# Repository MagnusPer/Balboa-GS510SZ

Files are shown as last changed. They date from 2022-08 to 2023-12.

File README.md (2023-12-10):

# Balboa-GS510SZ with panel VL700S

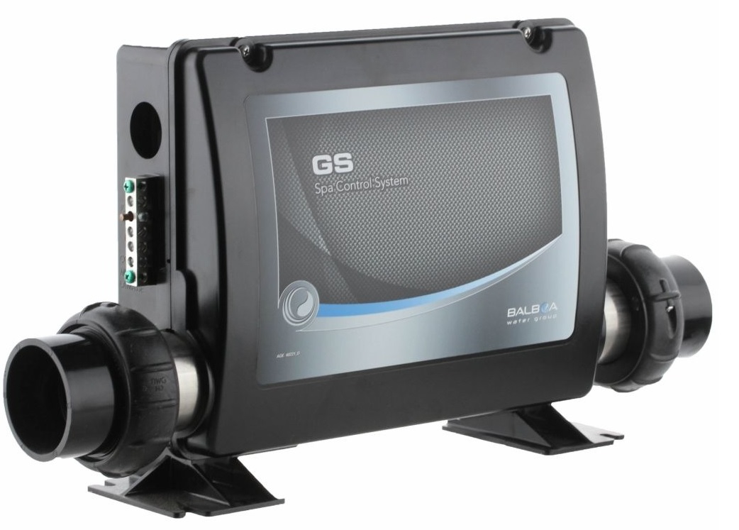
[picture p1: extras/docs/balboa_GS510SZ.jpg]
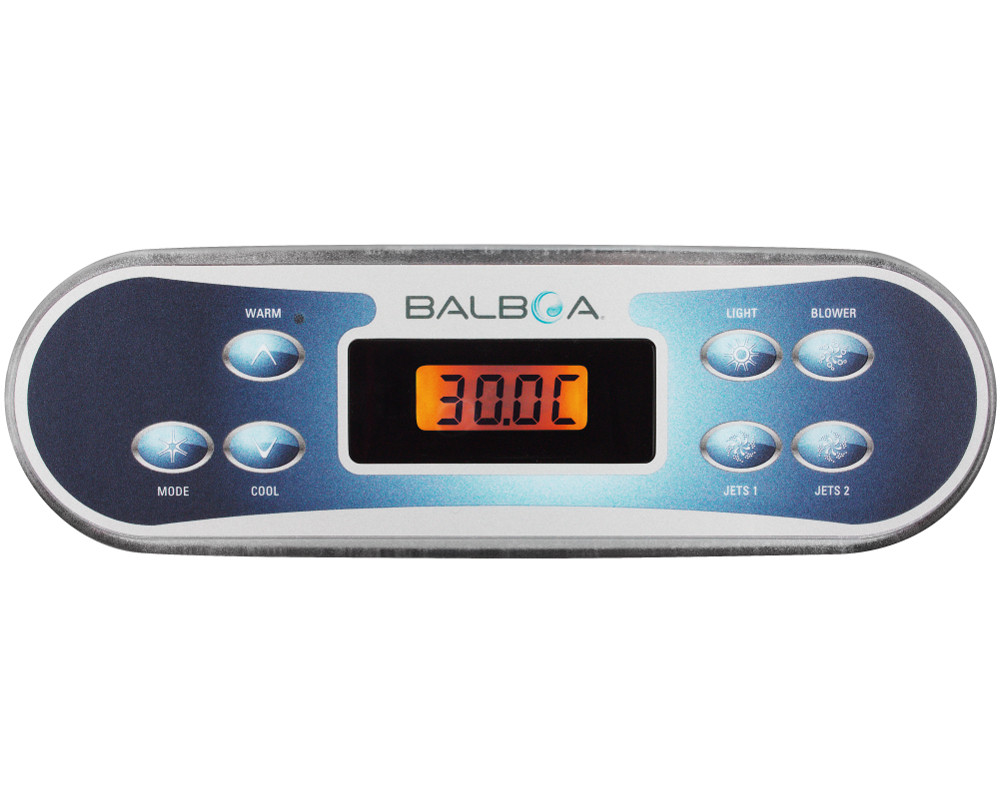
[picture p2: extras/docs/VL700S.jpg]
 

## Software
### version 1.3
 - New example sketch for Home Assistant users, thank you [netmindz](https://github.com/netmindz)   

### version 1.2
 - Updated a failure of the intepretation of "9" in `Balboa_GS_Interface.cpp`
 - Changed to [ElegantOTA](https://github.com/ayushsharma82/ElegantOTA) in `Balboa_GS_MQTT.ino` 
 - Added `Stop` and `Reset` MQTT interface in `Balboa_GS_MQTT.ino` 
### version 1.1 
 - New function `updateTemperature` added to set a temperature value instead of "push" button x number of times
 - Balboa_GS_MQTT sketch updated with [AsyncElegantOTA](https://github.com/ayushsharma82/AsyncElegantOTA)
### version 1.0 
- Basic functionality to read and set status using a **Balboa_GS** developed library. Two examples are provided, first with simple read and set functionality and the second using MQTT for remote access.

## RJ45 pins
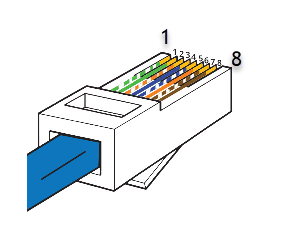
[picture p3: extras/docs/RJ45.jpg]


| PIN | Description | 
| --- | ---|
| PIN 1 | Functionality unclear!  |
| PIN 2 | Functionality unclear!  |
| PIN 3 | Button data |  
| PIN 4 | GND |
| PIN 5 | Display data | 
| PIN 6 | Clock |
| PIN 7 | 5 VDC |  
| PIN 8 | Floating output |

## Measurements 

### PIN 1 and 2 
PWM output from control system, same on both pins. Unclear functionality for these PINs still! Maybe some internal light supply? <br />  
50Hz, pk-pk=18v, mean 5V

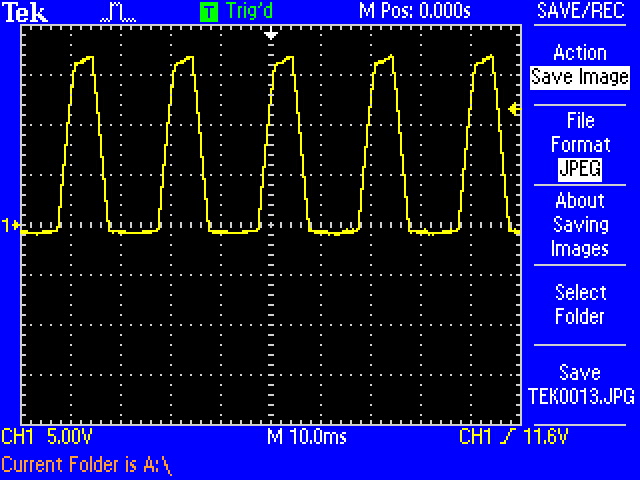
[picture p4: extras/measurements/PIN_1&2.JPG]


### PIN 6 (Yellow - clock), PIN 5 (Blue - display data), PIN 3 (Pink - button data) 

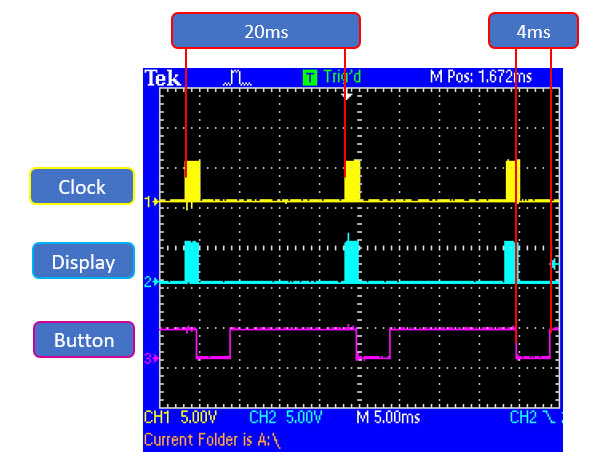
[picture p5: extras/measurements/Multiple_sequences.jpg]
   

<p align="center">
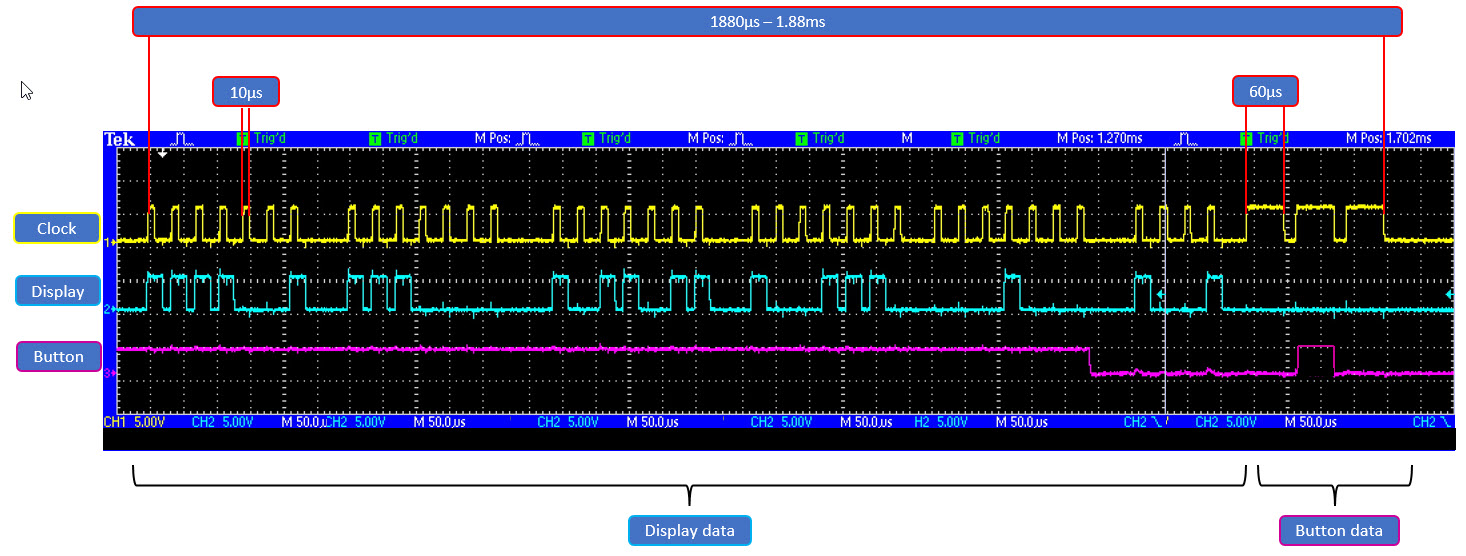
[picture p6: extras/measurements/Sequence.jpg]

</p>

#### Conclusion
- The clock is pulsing 7 times for each chunck of display data, totaly 39 bits and 3 times for button data. A complete cycle 42 pulses. <br />
- Totaly of 6 display data chunks in each cycle <br />
- Each cycle is repeted every 20 ms <br />
- One total cycle duration 1.88 ms
- Bit duration for display data is 10 microseconds for display data <br />
- Bit duration for button data is 60 microseconds <br />

#### Display Data
Display shows **37.5C** - How does that translates into the bitstream? The first 4 chunks is coded in BCD to 7 segment LCD (see reference) but only with 7 bits sinse the LSB always is (0). <br />
3 = 1111001(0) = 0x79  (Chunk 1) <br />
7 = 1110000(0) = 0x70  (Chunk 2) <br />
5 = 1011011(0) = 0x5B  (Chunk 3) <br />
C = 1001110(0) = 0x4E  (Chunk 4) <br />

| Chunk 1 - bit(0-6) | Chunk 2 - bit(7-13) | Chunk 3 - bit(14-20) | Chunk 4 - bit(21-27) | Chunk 5 - bit(28-34) | Chunk 6 - bit(35-38) | 
| --- | --- | --- | --- | --- | --- |
| LCD segment 1 |  LCD segment 2 | LCD Segment 3 | LCD segment 4 | 28 - Button down/up  | 35 - Heater | 
| | | | | 29 - ? | 36 - Pump 1 | 
| | | | | 30 - ? | 37 - Pump 2 |
| | | | | 31 - Standard mode | 38 - Light |
| | | | | 32 - ? | |
| | | | | 33 - ? | |
| | | | | 34 - ? | |
   
#### Button data 

|  Button |  Decoding bit(0-2) | 
| --- | --- |
| Mode | 0 0 1 |
| Temp up | 1 0 0 |
| Temp down | 1 0 1 |  
| Light | 0 1 1 |
| Pump 1 | 1 1 0 | 
| Pump 2 | 0 1 0 |
| Pump 3 | 1 1 1 |  

## Wiring

Since the display and controler unit hardware design is unknown an OR-gate is used to prevent damage if simultaneous HIGH/LOW levels from display and Arduino.

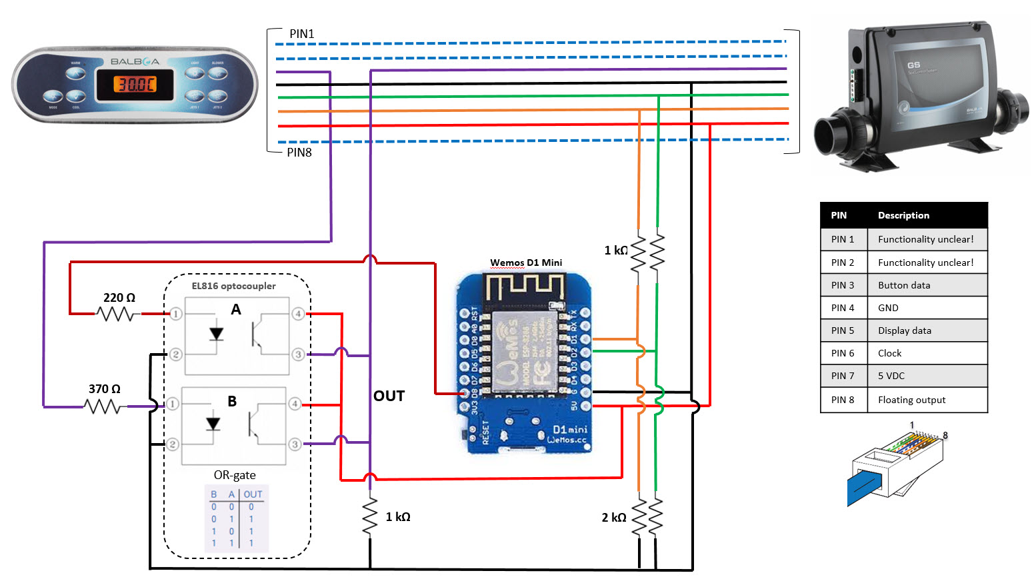
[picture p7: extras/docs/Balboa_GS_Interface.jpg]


## PCB fabrication

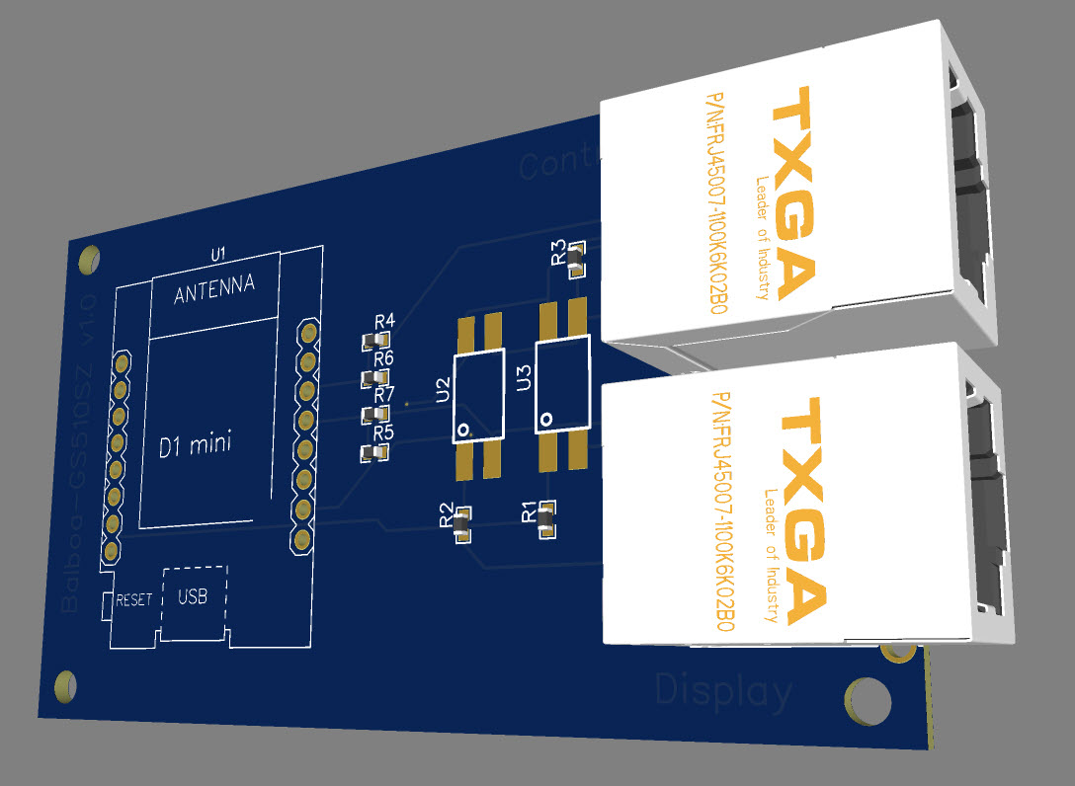
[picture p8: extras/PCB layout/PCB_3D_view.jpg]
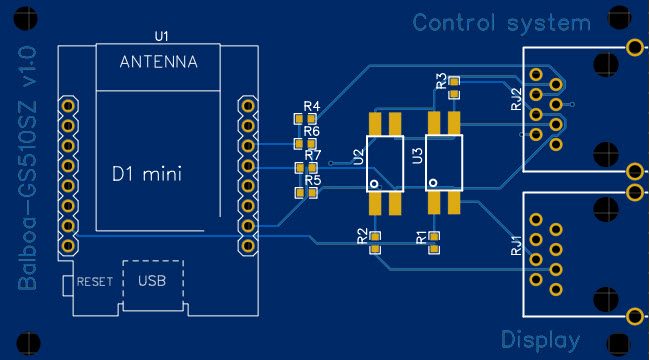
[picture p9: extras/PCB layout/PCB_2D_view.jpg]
 

Gerber files located here: [PCB Balboa-GS510SZ](https://github.com/MagnusPer/Balboa-GS510SZ/tree/main/extras/PCB%20layout )

## References of great help!
- https://github.com/NickB1/OpenSpa/blob/master/documents/Balboa/Balboa_Display_Measurements.pdf
- https://www.olivierhill.ca/archives/72-The-Internet-of-Spas.html
- https://create.arduino.cc/projecthub/meljr/7-segment-led-displays-102-using-a-shift-register-6b6976

## Other Balboa projects 
- GL2000 Series https://github.com/netmindz/balboa_GL_ML_spa_control
- BP Series https://github.com/ccutrer/balboa_worldwide_app
- GS523SZ https://github.com/Shuraxxx/-Balboa-GS523SZ-with-panel-VL801D-DeluxeSerie--MQTT

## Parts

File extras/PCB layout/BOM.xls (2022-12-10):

Comment | Designator | Footprint | JLCPCB Part #
FRJ45007-1100K6K02B0 | RJ1,RJ2 | RJ45-TH_FRJ45007-1100K6K02B0 | C2834418
EL816S1(D)(TA)-F | U2,U3 | OPTO-SMD-4P-4.58X6.5 | C181884
220 | R1 | R0603 | C22962
1k | R3,R4,R5 | R0603 | C21190
2k | R6,R7 | R0603 | C22975
370 | R2 | R0603 | C25194

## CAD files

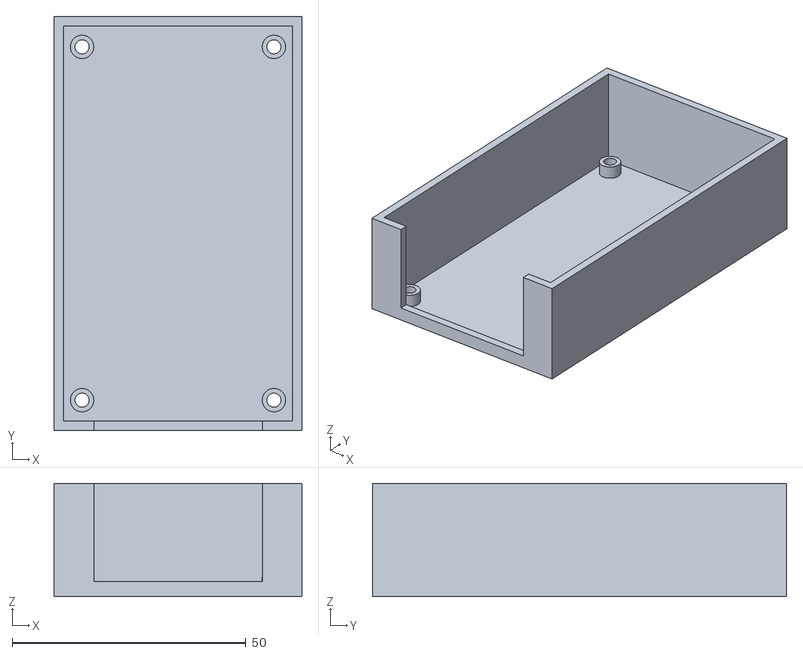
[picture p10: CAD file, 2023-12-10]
extras/Bottom.stl
53.0 x 88.5 x 24.2

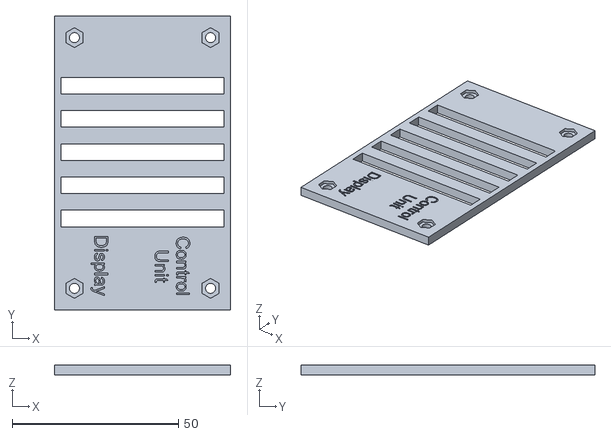
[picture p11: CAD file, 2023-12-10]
extras/Top.stl
53.0 x 88.5 x 3.00

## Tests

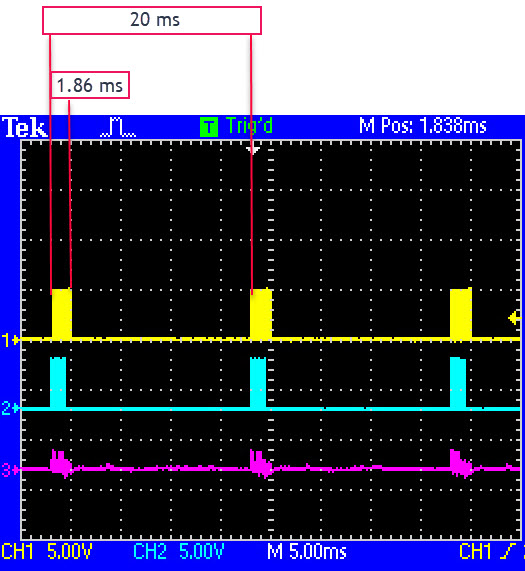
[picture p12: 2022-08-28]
extras/measurements/Cycles.JPG

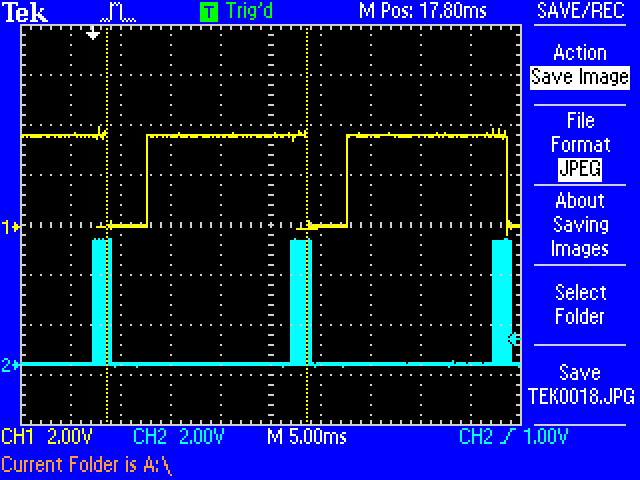
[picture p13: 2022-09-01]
extras/measurements/PIN3.JPG

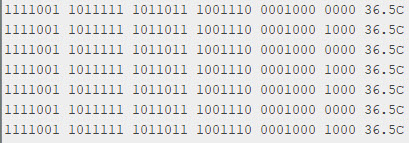
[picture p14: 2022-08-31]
extras/measurements/data_capture.JPG

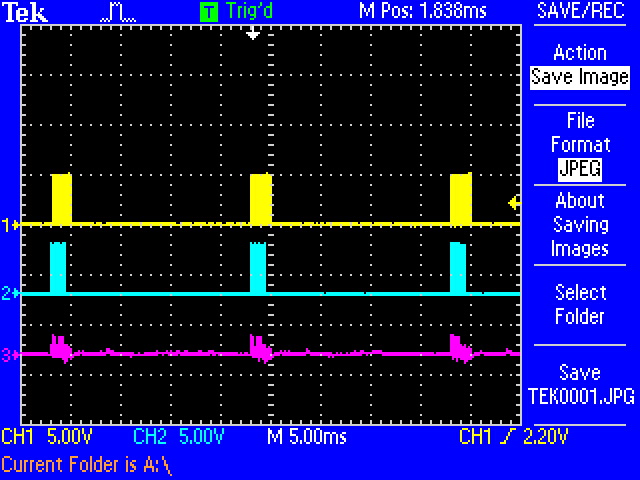
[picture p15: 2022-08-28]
extras/measurements/TEK0001.JPG

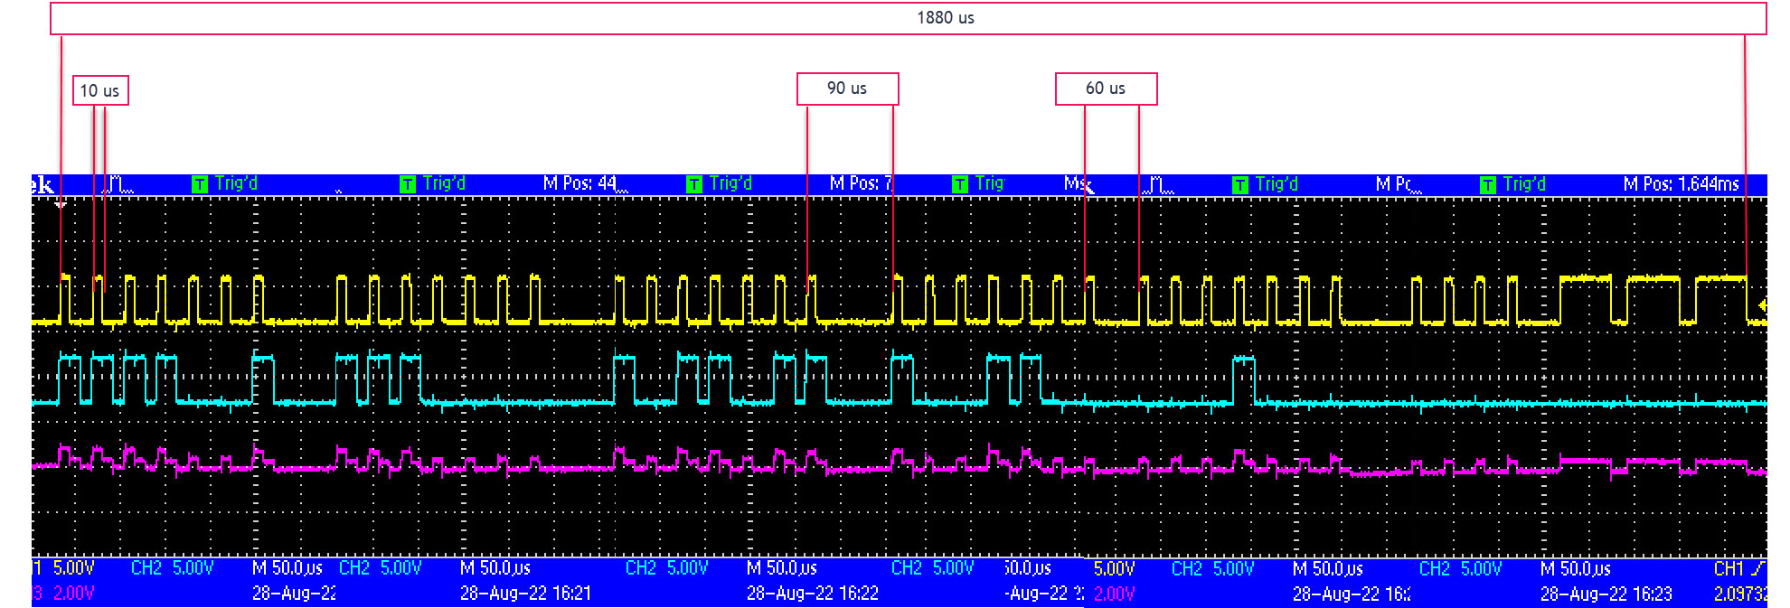
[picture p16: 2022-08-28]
extras/measurements/Complete Sequence.JPG

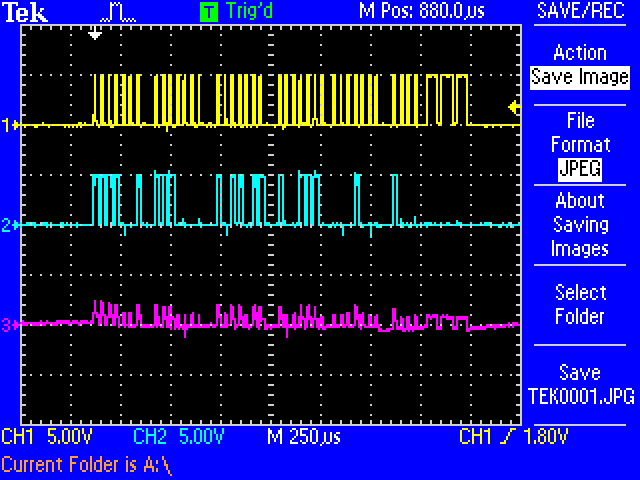
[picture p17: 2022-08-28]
extras/measurements/PIN6-PIN5-PIN8.JPG

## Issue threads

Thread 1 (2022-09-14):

Testing help

wictorwilen, 2022-09-14:
@MagnusPer - if you need a tester/contributor, please share the code. I'm all set with hardware to test this out!

MagnusPer, 2022-09-14:
Hi there!
First software delivery Phu! Have tested myself a couple of hours and it seems to work as expected so far. Mainly happy case scenario but anyway something is up and running :-)

Try this basic version out and give me some feedback and you are super welcome to contribute.

netmindz, 2022-09-15:
Great work turning this round so quickly

MagnusPer, 2022-09-16:
@netmindz - Thank you! Most of it was actually working with the oscilloscope to understand how the logic was connected. The library has now a limited scope of functionality as a start.

netmindz, 2022-09-16:
You say limited, but from quick look it appeared you had mapped all that the control panel can do.

Only bit that comes to mind for the library would higher level functions like setting a specific temp rather than just +/-

MagnusPer, 2022-09-16:
That is exactly what I working on now to set a specific temp instead of "push" the button x number of times

wictorwilen, 2022-09-16:
If electricity prices is decent this weekend I'll fill up my spa and start testing this! Amazing job so far

MagnusPer, 2022-09-16:
@wictorwilen - Before filling up the SPA with water you might test first the communication working as expected. I can imagine you will have some fault codes in the LCD display such low water etc. But at least you see that it works.

INFO: My top priority on this project is to be able to control when in time during the day the heater should be activated. This in order to save to money which i can spend on something more funnier:-)

netmindz, 2022-09-16:
Yeah that's why I want to get write access to my GL series. Have home assistant put into sleep overnight if the weather looks unsuitable the following evening or weekend day

Closed 2022-09-27.

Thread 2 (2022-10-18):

esphome.io support?

wjcloudy, 2022-10-18:
Hi, thanks for sharing this, going to try this on my own unit!

Just a thought, have you looked at writing this as a custom component in the popular esphome.io ecosystem?
This way the wifi stability, MQTT, HomeAssistant support, OTA, web UI & central management problem is all solved for you!

https://esphome.io/components/sensor/custom.html

MagnusPer, 2022-10-19:
Hi @wjcloudy
Happy you have found this library and please use and provide your feedback. I have used this for a couple of weeks and it serves my main purpose to control when in time the heater should be activated or not.

Your question on using esphome - I have myself not used and by that not have any experience. Feel free to adapt the example code and make a proposal which we can evaluate and provide to the community as an additional example.

wjcloudy, 2022-10-19:
Thanks, will look into it. I also want to use for controlling heater on time. I presume you achieve this by ramping the temp up during periods you want to use power and down at other times?. Have you found a way to adjust the minimum set point?

MagnusPer, 2022-10-19:
Yes - I change the temperature dependent if I want to heat or not. My settings is right now to toggle between 37 and 27 degrees depending on electrical price using the Homey automation Hub

MagnusPer, 2022-12-13:
CLOSED - No activity

Closed 2022-12-13.

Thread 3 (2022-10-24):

VS series compatibility?

kernel610, 2022-10-24:
Any idea if this should work with the VS series Balboa controllers that also use the RJ45? I was about to order the PCB to test it out but wanted to see if you've heard anything from others or foresee any challenges? If not, I can test and provide back an update.

Is there a Discord or someone to provide updates if I test it as opposed to cluttering up your Issues?

MagnusPer, 2022-10-25:
Hi,
Unfortunately no idea if the Balboa **VS** system is compatible with the GS or not. But after some minutes googling the control system PCB seams at least similar.

As information there are other repositories for other balboa systems, you might can go through those and see if any have asked the same question as you have:
Balboa **GL** -  https://github.com/netmindz/balboa_GL_ML_spa_control
Balboa **BP** -  https://github.com/ccutrer/balboa_worldwide_app

I haven't set up a Discord area for this development, I think we can trace it through issues within this repository so far. But if the community grows, I'll keep that in mind

netmindz, 2022-10-25:
If you look at the manual for at least some of the VS series to see what Topside panels they are compatible with, then look at what control units they work with, I see GS units listed.

What is your exact model of controller and topside panel?

The key thing really is both the GS and GL project are really emulating the panel for their respective controllers

MagnusPer, 2022-10-25:
When reading the topside panel documentation I use for my GS-serie [VL700S](https://github.com/MagnusPer/Balboa-GS510SZ/blob/main/extras/docs/Balboa-Panel-VL700S.pdf) I found here that both GS and VS control system is compatible

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

By that I think this library should work also for the Balboa **VS** serie

kernel610, 2022-10-25:
Controller model is VS501SZ which appears to be covered with the link and screenshot Magnus provided. Topside panel is in rough shape but documentation for the controller shows VL401, VL403, or VL200.

I'm going to order the PCB and give it a try! I'll keep you updated through this thread. Thanks again for the effort put into this!

MagnusPer, 2022-10-25:
Minimum order is 5 PCBs, I have one available which I could send by post to you. Give me your adress by mail magnus_p@live.se

Closed 2022-12-23.

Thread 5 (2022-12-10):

BOM list for PCB?

thoby1, 2022-12-10:
Very interesting project. Thought I would test this, but have limited electronics knowledge.
Could you attach a BOM list so that it would be easier to order all the necessary components for the PCB board?

cbakkerprive, 2022-12-10:
Wow, cool! I too am definitely interested in the BOM list.

MagnusPer, 2022-12-10:
I have been using this for a couple of months now and it works as I expected with my main purpose to heat the SPA during the cheapest hours.

The BOM list hopefully explained in the [Wiring](https://github.com/MagnusPer/Balboa-GS510SZ#wiring) section. What you need is the following:

3 pcs  - 1 kOhm resistor
2 pcs  - 2 kOhm resistor
1 pcs  - 220 Ohm resistor
1 pcs  - 370 ohm resistor
2 pcs -  EL816 optocoupler
1 pcs - Wemos D1 mini
1 pcs - RJ45 cable

thoby1, 2022-12-10:
Cool to hear it works! The use case with turning the heater on and off during low and high prices was exactly what I had in mind.

When it comes to purchase of parts there seems to be so much extra specifications that makes it hard to choose. For resistors for example there are spec for Voltage and Watt. Take the 2kOhm for example, will this item work:
**NQ06W4F2001T5E**
[](https://jlcpcb.com/partdetail/1050181-NQ06W4F2001T5E/C965049)

MagnusPer, 2022-12-10:
I uploaded the BOM list [PCB layout](https://github.com/MagnusPer/Balboa-GS510SZ/tree/main/extras/PCB%20layout) I used when I purchased the PCB, hope this helps

cbakkerprive, 2022-12-10:
Thank you!
Can you also provide the CPL file so I can order assembled from JLCPCB?

MagnusPer, 2022-12-10:
@cbakkerprive - Not sure what you mean with the CPL file but I guess its the [PickAndPlace](https://github.com/MagnusPer/Balboa-GS510SZ/blob/main/extras/PCB%20layout/PickAndPlace_PCB_Balboa-%20GS510SZ_2022-12-10.csv) file?

cbakkerprive, 2022-12-11:
Thanks MagnusPer!
Indeed I did the PickAndPlace File.
As stated I try to order the assembled PCB from JLCPCB.
I did uploaded the 3 files to JLCPCB, but unfortunately after selecting the BOM and the PickAndPlace file (and select Next) I get the following error:

_Incorrect format
File parsing timeout. Please try again later.__

Maybe I should try to open the gerber file in the EasyEDA designer myself.
Thanks anyway.

MagnusPer, 2022-12-11:
@cbakkerprive - I think it's better you try yourself to create the PCB in e.g. EasyEda with the help of the Gerber files provided. I remember I needed to replace and change the optocouplers component due to missing parts in the factory. When you succeed to place the order please help others here by attaching your PCB production files.

If you have any questions I'm here to help the best I can!

thoby1, 2022-12-30:
I havesuccessfuly completed a order at JLCPCB with the "BOM.xls" and "PickAndPlace_PCB_Balboa-GS510SZ_2022-12-10.csv" file. This issue can be colsed.

Closed 2022-12-30.

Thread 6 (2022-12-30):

Support for VL600S panel?

thoby1, 2022-12-30:
I tested the software against a VL600S panel. It seems to give the correct status messages, but when I try to send commands the display stops working. Then only a gray background is displayed without any text. When this happens, I have to turn off the power and disconnect the circuit board with the Arduino. Then when I turn on the power again with the original setup, the display works fine. Have tried the "stop" and "reset" function, but it has no effect on the issue.

MagnusPer, 2022-12-30:
To start somewhere...
If you press the display button when the circuit board is connected, does the e.g. jets starts or temperature change? by this I want to understand if the connection is OK between the controller unit and the display with the circuit board connected.

thoby1, 2022-12-30:
I am using the MQTT example.

Looks like the same thing happens when you press the control panel. Also managed to provoke the error by just waiting a few minutes without pressing a single button or sending any command. I think you are on to something about there not being a good connection between the control unit and the display, when the circuit board is connected. I have tested the TP cables with a network cable tester and they worked fine. Also tested the circuit board with the same cable tester. There I got connection on all pins except for pin number 3.

MagnusPer, 2022-12-31:
Yes - something is wrong since you not manage to press the display button.

Have you used ordinary TP cables? They normally have crossed lines!

You can not measure line 3 since the optocoupler requires 5V to close. you could provoke that by manually add 5V and GND on the bench to check

thoby1, 2023-01-01:
- I’m using the original flat cable that comes from the display and my own twisted pair cat 6 straight cable to the control system. The cables has a straight connection on etch pin. Should I use only flat cables and not the one that has twisted pairs? The two cables work together if I disconnect the circuit board and connect them with a RJ45 cable extender.

- Tested the optocoupler by giving it 5V from line 3 on RJ1. That gave me a signal on line 3 from RJ2.

- I have wired the display the RJ1 connector (it is marked with “Display” on the circuit board) and the control system to RJ2.

I see that I am using version 3 of the Wemos D1 mini, but in your wiring diagram it shows version 4. Will that be a problem?

To be more specific in the issue. The system seems to be working fine during the hot tub startup sequence when I turn the fuse on. Then I get MQTT messages with water temperature and pump status etc. After the startup the display begins to flash between showing the water temperature and just a gray background. Eventually just ending up in showing a gray background. This happens regardless of me sending any commands or not. To correct the issue I have to put everything back to the origianl setup. Since the cables work fine with just a cable extender and not on the circuit board could there be too much resistance on some of the pins?

MagnusPer, 2023-01-02:
Seems the TP-cables are ok when a RJ45 cable extender is used. I think it's more likely something with the circuit board. If we suspect the Wemos then you can disconnect that from the board since the board should work without it, check the [wiring diagram](https://github.com/MagnusPer/Balboa-GS510SZ#wiring).

thoby1, 2023-01-02:
Tested a circuit board without Wemos and it worked fine. All buttons and display worked as they should.

Should the Wemos have an external power supply? While testing I only have only connected the two TP cables. They have 5V on pin 7 and ground on pin 4. I was wondering if the Wemos draws too much power.

MagnusPer, 2023-01-02:
Ok, we are closing in!
To be sure about the Wemos you are using. Is this the ESP8266 or the newer ESP32 version?
A guess is the Wemos restarts and might cause the problem. To check this connect your computer an log via the serial interface to check what’s happening

thoby1, 2023-01-04:
I have now tested the Balboa Read example software and connected it to a PC for debugging.

It worked fine from the software side. I saw the status and could start and stop the pump, turn lights on and off, etc.

When I pressed the display, it behaved strangely. It didn't always react and if it did it seemed as if the buttons had been given a different function. If I pressed “Pump 1” it looked like I pressed “Temp up”.
Finally, I ended up with the same error. Showing a gray background in the displayed again.

The difference in this test scenario is that Wemos is supplied with external power from the USB cable and that this software do not use the WiFi module. So maybe there is something with the power?

Also, if I used the board “LOLIN(WeMos) D1 R1” the software did not work. I ended up using the “LOLIN(WEMOS) D1 R2 & mini” board config.

MagnusPer, 2023-01-04:
I just thinking about the VL600S (6 button) panel and the difference compared to the VL700S (7 button) I have - when reading the [Balboa-GS510SZ](https://github.com/MagnusPer/Balboa-GS510SZ/blob/main/extras/docs/Balboa-GS510SZ.pdf) documentation there are some jumper settings to configure the control system with depending on panel configuration. And if this effects the way the commands is sent??

> It worked fine from the software side. I saw the status and could start and stop the pump, turn lights on and off, etc.

Need to double check this, do you mean when entering the write commands using the serial monitor the the activations is correct?

> When I pressed the display, it behaved strangely.

This is really strange since the signals should go straight through the optocoupler - see the [wiring diagram](https://github.com/MagnusPer/Balboa-GS510SZ#wiring). Like when the Wemos was dismounted.

Did you order more then one circuit board, have you tried another one?

thoby1, 2023-01-07:
I have limied knowlage about this but I think there is something wrong with the circuit board. When I tested with voltage on the Wemos, it outputs 5V on pin 7 and 4 (ground) (RJ2). If I did the opposite and put voltage on pin 7 and 4 at RJ2, I only got about 1V on pin 8 and 7 on the Wemos. Suspect that there may be something wrong with the common ground somehow. Because if I tested pin 8 on Wemos against pin 4 on RJ2, I got 5V. Tried different places where I had access to common ground such as on one side of R3 I also only got 1V.

When it comes to the jumper settings on the motherboard such as J12, I interpret it as which software should run. I use this setting:

**Jumper must be on Pins 1 and 2 for GS51xZ/GS52xZ/GS5xxSZ/GS5xxDZ software.**

I have a spare circuit board that I have tested without Wemos and it works fine. Have ordered a new Wemos v4.0 now. Will test again when I get it. I believe that it will work then, because when I tested with the Read example and sent commands via the serial interface, I was able to set the temperature, turn the pump on and off and turn on the light. The Wemos never seemed to restart.

MagnusPer, 2023-01-07:
Tricky when I not myself can measure the circuit board. What I at least have done is to update the [wiring diagram](https://github.com/MagnusPer/Balboa-GS510SZ/blob/main/README.md#wiring) to clarify the Vcc +5V and ground connections.

You are on the correct track, verifying piece per piece, at least we have learned and have zoomed in where the problem is located. If possible, please take a picture on your board with the Wemos mounted and paste it here.

Give me an update when you have tested with the new Wemos.

thoby1, 2023-01-13:
I got the same error now with a new circuit board with v.4.0 of Wemos. My problem is that I don't get enough voltage to the Wemos from RJ1 or RJ2. My test setup is a USB mobile charger which provides 5v. It works if I connect the USB to the Wemos, but if I apply voltage to pins 7 and 4 on RJ1 or RJ2, I only get about 1v on the Wemos. I have soldered all the pins from the Wemos firmly to the circuit board, although from the drawing only pins 3, 4, 7, 8 and 15 needs to be connected. Will that be a problem? Holes have been made for all the pins on the circuit board, so I assumed that the ones that are not in use are isolated.

Have attached a picture of the first circuit board. The soldering doesn't look so good after I've tried soldering the Wemos off and on again.

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

MagnusPer, 2023-01-13:
The unused pins is not connected to anything, no problems to solder them.

When measure with a standard multimeter it takes the average of the voltage, since it is a communication line you will never have 5V since this is the peak value.

I need to do my own bench test setup to guide you further. I will be back home on Sunday, so expert som days until I have some data to provide.

But until then - I tried to zoom in on the Wemos board to look after some data, can you read ESP8266 or ESP32 on the chip?

thoby1, 2023-01-24:
Installed version 4 of Wemos LOLIN D1 mini [https://www.wemos.cc/en/latest/d1/d1_mini.html](url) on a diffrent circuit board and now it is working as expected. Guess I was just unlucky with either my old Wemos or the circuit board. Regardless. The VL600S display panel can also be used with this project.

Closed 2023-01-24.

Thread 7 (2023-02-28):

Compability with GS501Z and VL200?

richardtjena, 2023-02-28:
Hi!

I have a Balboa GS501Z-control system with VL200 duplex display which uses RJ45 but only have four buttons.

Do we know if the data protocol is the same regardless if the display is a Duplex- (GS5xxZ), Standard- (GS5xxSZ), or Deluxepanel (GS5xxDZ-unit)?

BR

MagnusPer, 2023-02-28:
@richardtjena  - Welcome in here to this repository!

When reading the specs of the control system [GS501SZ](https://www.balboawatergroup.com/getdoc.cfm?id=2160) and [GS510Z](https://www.balboawatergroup.com/getdoc.cfm?id=2169) there are some differences as you mentioned where the VL200 panel has less buttons.

To be honest, I have no idea if this will work or not, but my guess based on the documentation is that it should work as both features like the circuit board layout seem to be pretty similar.

The best answer is if you make a try - The hardware cost is where low!

MagnusPer, 2023-03-03:
Closing this issue since this repository does not support Balboa GS501Z-control system with VL200 panel

richardtjena, 2023-04-10:
@MagnusPer was it a user with a public repo? Any chance you can point me to his direction.

I also thought about flipping the J12 jumper in the control unit but don't know if it would have any effect without changing the ROM.

StarkJohan, 2024-04-15:
I have the same setup and the protocols must be very similar. To avoid doing the work someone else already has done, please put me in contact with anyone that might help: johan@punktvvv.se

netmindz, 2024-04-18:
The way to know about compatibility is to think about the fact we are emulating a panel, so if you look at which official panels are compatible with which controllers you know that they must use the same communication

StarkJohan, 2024-04-21:
I'm using the VL240 panel and the protocol is indeed similar but there's a few big differences. I've outlined them in another issue.
In short it will not be possible to use this repo or the hardware without rather big changes.

Closed 2023-03-03.

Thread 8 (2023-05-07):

Confirming ground pin?

techoguy, 2023-05-07:
Hi, just curious how you were able to confirm which pin was the ground. I'm currently sniffing my spa panel bus and it seems to have a similar protocol (though different) compared to yours. Mine has only 3 groups of 7 data and handles the buttons the same way as yours. But I'm trying to confirm which pin is the ground pin.

My protocol has a different odd case when the clock is held high until the next batch of data. Still trying to figure out why it does that (it might be indicating the heater on LED on the panel, but not sure yet).

I'm still annalizing my data to see how I want to implement this but seems like I might be able to use yours as a baseline. Thanks for the work you've already put into this.

MagnusPer, 2023-05-08:
Hi,
Great this repository can advice and help you with your project. The work I did was more based on "exclusion method" where I finally understood the SPA behavior and the usage of each pin. To find the ground pin you can measure against the control unit ground which should have the same.

netmindz, 2023-08-07:
What model do you have @techoguy ?

One way to confirm ground is with the power turned off use a multi meter to check for continuity between that pin and the ground plane of the PCB

techoguy, 2023-08-09:
@netmindz I have a Sundance Camden with 780 Series I-Touch Controls. I think it's about 10-15 years old. Below is a picture of the current signals.

- there is an 8 pin connector going to the control panel and an empty RJ45 plug
- Pins 1-6 are the same between both connectors, but pins 7 and 8 are not
- the control board sends a sequence every 100ms (3 bytes of data to the touch panel, 7 bits from the touch panel for button presses)

**Pins:**

1. 5v
2. GND
3.  Data
4.  Clock
5.  Select (active low)
6. Button Data
7. (Not sure) maybe a device select?
8. (Not sure) maybe a device select?

Signal Example:
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

Picture of control board connectors:
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

Closed 2023-08-06.

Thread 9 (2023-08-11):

how to determine if set temperature is displayed vs current water temperature?

techoguy, 2023-08-11:
Hi @MagnusPer I'm reading over the code to see if I can start from your code or if it'll be easier to start from scratch. Curious, on your display, when you press up or down to change the temperature and the display temporarily displays the set temperature vs the current water temperature, how does the ESP device know which temperature is displayed? On my spa, there appears to be no pattern or indicator in the messages to the control panel when the set temperature is displayed vs the current temperature which means I can't really tell which temperature is displayed unless I also have the button signals as inputs to know someone at the panel is changing the set temperature. curious how you're dealing with this.

Thanks!

MagnusPer, 2023-08-11:
Hi,
There is a trigger `displayButton` when the up/down button is pressed on the display. By this I can understand if it’s the water temperature or set temperature that is shown.

Closed 2023-08-13.

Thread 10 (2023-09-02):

HowTo

duczz, 2023-09-02:
Hey, i have this baboa Whirlpool too and wanna try these, but iam missing a HowTo.
Currently i have flashed your Project to a wemos Mini (with my settings) but i have no entitied in the homeassistant mqtt server.

What are ne next steps? Docker witch bwa?

netmindz, 2023-09-02:
Have you tried the simple read example first to confirm the basic setup works first?

You don't mention if you have any existing Home Assistant setup already on place. You will need that and follow an appropriate guide to setup MQTT with Home Assistant

There are many different ways for this depending on how/where you are running HA

Once that's setup, you should see the spa under MQTT inside HA

MagnusPer, 2023-09-02:
Hi and happy that you are interested in this library.

Firstly, Have you set your credentials in the code for the MQTT broker?
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

If so check that MQTT messages coming in from the SPA using a MQTT tool like http://mqtt-explorer.com/

duczz, 2023-09-02:
Thanks for reply guys.
I have a MQTT Integration on my homeassitant, these i have enters already in the config, thats why i see via MQTT Explorer the Spa Parameters, but not on homeasssitant
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

MagnusPer, 2023-09-02:
Sorry, I do not have HA instead I use Homey so the integration to HA using MQTT I can not help you with

duczz, 2023-09-02:
okay thank, so the next steps are only to let create the PCB layout and than put the j1 in the new medoul and j2 from the modul to j1 from the balboa right? not more to do?

netmindz, 2023-09-02:
You could use with HA with just the raw MQTT, but it's *much* easier if you have a proper device registered in HA

netmindz, 2023-09-02:
Ok, that's the basic read-only example up there now

![Uploading Screenshot from 2023-09-02 17-55-29.png…]()

duczz, 2023-09-02:
Perfect, the other will follow too?

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

netmindz, 2023-09-02:
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

netmindz, 2023-09-02:
Latest version with buttons too - untested as I don't own that tub

duczz, 2023-09-05:
to close the ticket, can someone answer my question?
so i need to let create the PCB layout and than put the j1 in the new modul and j2 from the modul back to j1 from the balboa right, than im finished?

can i control than the modies too and set the time for filter?

MagnusPer, 2023-09-06:
@duczz - Between the display and the control system there is a cable with an RJ45 connector. Disconnect that from the Control system and place PCB in between. You need to create/buy the cable with RJ45 connectors between J2 -> Control system, NOTE that should have straight lines and not crossed as in a normal TP-cable.

**DISPLAY**-------->(J1)  **PCB**  (J2)--------->**Control system**

There are no functions created to change modes or set filter times etc. The library however supports buttons to be pressed so theoretically it should be possible - see the section [button data ](https://github.com/MagnusPer/Balboa-GS510SZ#button-data)

I hope this mini guide will help you to get it up and running

duczz, 2023-09-06:
Perfect thank you Magnus.
@netmindz can you add all Buttons on this display to homeassitant? Than i can create automatisations to set mode / filtertimes etc.

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

netmindz, 2023-09-06:
I won't be adding any more to the code, if the buttons are supported by the library then it should be easy to follow the current examples.. If not, then update the library part of the code too

Create a fork then and then submit a PR

duczz, 2023-09-06:
@netmindz alright, thanks for the first homeAsssitant port steps.
@MagnusPer are you able to update these? it looks like all buttons would be exist. i'm to noobie to port these :(
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

MagnusPer, 2023-09-06:
Sorry, I don’t have the knowledge how the Home Assistant works. The library support the “Mode” button and what I see is included in the HA example. The only missing piece is to add a HA button to trigger the mode.

knogler, 2023-10-21:
@duczz have you found a solution?

netmindz, 2023-10-21:
To add a button for pump3, just copy and paste what's listed for pump2

```
pump2.setName("Pump2");
pump2Button.setName("Pump2");
pump2Button.onCommand(onButtonPress);

```

but name pump3. Do same for any other buttons you want such as Mode

netmindz, 2023-10-21:
As well as the definition of he button

`HAButton pump2Button("Pump2");`

knogler, 2023-10-21:
Thanks for the answer, I probably could have done that.

Unfortunately, setting the temperature is not displayed. somehow the variable “setTemperature” is missing from the homeassist file. And unfortunately I don't know how to create this in order to be able to regulate it.

duczz, 2023-10-25:
@knogler nope, i was not able to migrate it complet to HomeAsssitant. I think this will never be done ^^ (i'm no developer :/)

netmindz, 2023-10-30:
Try this version @knogler  https://github.com/MagnusPer/Balboa-GS510SZ/pull/13

duczz, 2023-11-09:
@knogler Could you test it successfully?

J0E-Cool, 2023-11-15:
Hi @all,
just a dumb question ;)  and sorry to reuse this chat...
I've already built the circuit on a stripboard 🙈, but now I'm thinking about, how I could test it with the still installed display VL100 and control board GS100... because, I guess, I've to adapt the programming.
Do you have some tips, lessons learned, how you did/do that?
Thanks :)

knogler, 2023-11-17:
Sorry for my late response. and thanks for coding. Unfortunately I haven't had time to test yet. I also have to see how I can get the software modified so that it runs with Balboa-MGS504DZ with panel VL700S (MAY800D). As soon as I have more information, I'll let you know.

netmindz, 2023-11-17:
The model of top panel shouldn't really matter too much as we are emulating a panel. So what matters most is compatibility with the controller and the protocol it's speaking. Different models in the same range should use the same protocol so it shouldn't need code change.

What you might find is that your tub might only have 1 pump not two, so you mind find that pressuring pump2 might trigger the blower, just as if you had the wrong overlay applied to your top panel for your particular configuration

MagnusPer, 2023-11-17:
> Hi @ALL, just a dumb question ;) and sorry to reuse this chat... I've already built the circuit on a stripboard 🙈, but now I'm thinking about, how I could test it with the still installed display VL100 and control board GS100... because, I guess, I've to adapt the programming. Do you have some tips, lessons learned, how you did/do that? Thanks :)

[@JOE-cool](https://github.com/J0E-Cool)

1) Start to just connect the circuit board to see everything works by manually press the panel buttons.
2) Easiest is to use example code [Balboa_GS_Read](https://github.com/MagnusPer/Balboa-GS510SZ/tree/main/examples/Balboa_GS_Read) and monitor via the serial monitor in [Arduino IDE ](https://docs.arduino.cc/software/ide-v2/tutorials/ide-v2-serial-monitor) if data is observed.
3) You can also use the example code via the serial monitor input to activate button presses according to the [code](https://github.com/MagnusPer/Balboa-GS510SZ/blob/main/examples/Balboa_GS_Read/Balboa_GS_Read.ino). Example is `4` to activate light
4) Now its time for remote access and automation. Depending of your knowledge and needs you have either the MQTT or HomeAssistant to work with

Good luck!

J0E-Cool, 2023-11-17:
@MagnusPer thank you, helps me a lot :) I hope I can continue this weekend, if the weather allows.
For the automation part, I've still to decide which one would fit best (don't have any in place), but step-by-step ;)

ggtimtom, 2024-01-05:
Hello, i also try to make my GS523DZ with Panel VL802DZ smart. I hope the protocol will be similar.
I will start when the weather is fine.

malu254, 2024-01-05:
> Hello, i also try to make my GS523DZ with Panel VL802DZ smart. I hope the protocol will be similar. I will start when the weather is fine.

Hello,
I think you need the Version from here https://github.com/Shuraxxx/-Balboa-GS523SZ-with-panel-VL801D-DeluxeSerie--MQTT
The Hardware which you need will be the same

duczz, 2024-01-13:
i try to build curretnly my lovelance Layout for the Summer. :)
Is it possbile to switch all Buttons with on/off function into a switch? what i need to edit for that?

MagnusPer, 2024-01-13:
I using NodeRed as dashboard for my home automation. In NodeRed I create buttons triggering the MQTT commands and subscribe to MQTT status. Simular should be possible to do using Lovelance.

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

duczz, 2024-01-13:
Thanksmagnus, I had hoped that we could change habutton to haswitch in the *.ino File direct but i dont know If this works. Maybe @netmindz know it? :) (i dont know If haswitch exists in this program language)

netmindz, 2024-01-13:
Yes there is @duczz  - see https://github.com/netmindz/balboa_GL_ML_spa_control/blob/7e193eb2708c2803dda82cae5e14056a8bfcb445/sensor/src/sensor.cpp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

The key thing is if you aren't just a button, then you need to know the current state, so it's not just swapping the type, but still pretty simple to do. See standalone example https://github.com/dawidchyrzynski/arduino-home-assistant/blob/main/examples/light/light.ino

netmindz, 2024-01-13:
I haven't tested the code, but it will be something along the lines of this https://github.com/netmindz/Balboa-GS510SZ/commit/4d32135e64c111bf3d1619eb5a832677b0603a93

duczz, 2024-01-14:
i have created on netmindz top tipps and example (much thanks without i cant do this) a new version, magnus can you create a new "Balboa_GS_HomeAssistant_DEV.ino" with this content? Would be create when someone can test it, my platine is not delivered :(
https://pastebin.com/7bMn9JAM

Someone knows why line 237 is commented out?

netmindz, 2024-01-14:
@duczz  - I'm not familiar with this specific controller, but I know on some spas the buttons have multiple functions, so even if there are switches for the pumps, it might not be wise also to remove the ability to send button presses, unless you know for sure that you only need mode and temp +/-

As for your onSwitchCommand, this needs to look to see **which** switch you are trying to change and then read the right state, you currently are reading the state of the light.

For example of checking the sender see https://github.com/netmindz/balboa_GL_ML_spa_control/blob/7e193eb2708c2803dda82cae5e14056a8bfcb445/sensor/src/sensor.cpp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

MagnusPer, 2024-01-14:
@duczz - When you have a working and tested example you can do a Pull Request and then I can approve it to be added

duczz, 2024-01-17:
okay thanks netminz, i tried, but that programming is to high for me im out ^^

awallace24335, 2024-01-27:
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

Just to confirm, can this be a normal patch cable or do the pairs have to be untwisted?

Thank you

knogler, 2024-01-28:
yes, it's a normal patch cable

jarnodrenth, 2024-11-24:
> Sorry, I do not have HA instead I use Homey so the integration to HA using MQTT I can not help you with

 Can you tell me what you use for homey?

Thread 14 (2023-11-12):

No possibility to buy the PCB via JLPCB

malu254, 2023-11-12:
Hello @MagnusPer , do you have any of your circuit boards for the Balboa control system left? Unfortunately, the Everlight Elec EL816S1(D)(TA)-F is currently not available for purchase via JLPCB. I already have the WemosD1Mini, so I would only need the board with the soldered SMD components.
If you still have a circuit board, how much would it cost including shipping to Germany?

Sorry for opening an issue, but Github has unfortunately removed the private message tab.

BR
malu254

MagnusPer, 2023-11-12:
@malu254  - Unfortunately I have no extra circuit board. But the JLPCB must be able to give you a proposal of a similar one since that optocoupler is very regular.

malu254, 2023-11-12:
Ok, too bad, unfortunately JLPCB can't suggest any others, or am I missing something?
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

Sh4d, 2023-11-18:
You can order them from China for relatively cheap - https://www.aliexpress.com/item/1005004701331738.html?spm=a2g0o.order_list.order_list_main.71.48c918022AP3k2

I got mine to Canada in about 2 weeks.

malu254, 2023-11-26:
@MagnusPer @Sh4d thanks for your Help. I managed it to switch the Optocoupplers to similar ones

kernel610, 2024-01-12:
> @MagnusPer @Sh4d thanks for your Help. I managed it to switch the Optocoupplers to similar ones

@malu254 What did you choose as the replacement that worked? I'm placing an order for another built board since my board shorted out from water intrusion in the box. I'm seeing the same stock shortage message on the octocoupler.

malu254, 2024-01-12:
> > @MagnusPer @Sh4d thanks for your Help. I managed it to switch the Optocoupplers to similar ones
>
> @malu254 What did you choose as the replacement that worked? I'm placing an order for another built board since my board shorted out from water intrusion in the box. I'm seeing the same stock shortage message on the optocoupler.

@kernel610 i used this ones: TLP785(BL-TP6,F(C

But if you want i would have to spare PCBs to Sell. They would be completely finished except for the D1 mini Micro Controller

PerssonNiklas, 2024-07-29:
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

You dont happend to have one left for sale perhaps? Old thread, worth a shot!

colsonpete, 2024-07-29:
I have a couple of the base boards (no D1 Mini) going spare if you are interested?

I haven't got one working yet, but suspect that's down to me trying to to get it to work between a GS515Z controller and a VL406T panel.

PerssonNiklas, 2024-07-30:
> I have a couple of the base boards (no D1 Mini) going spare if you are interested?
>
> I haven't got one working yet, but suspect that's down to me trying to to get it to work between a GS515Z controller and a VL406T panel.

Whats your email so we can get in touch?

colsonpete, 2024-07-30:
Hi NiklasMy email is peter Dot colson at pc-ss dot co dot ukKind regardsPeter ColsonOn 30 Jul 2024, at 21:54, PerssonNiklas ***@***.***> wrote:

I have a couple of the base boards (no D1 Mini) going spare if you are interested?
I haven't got one working yet, but suspect that's down to me trying to to get it to work between a GS515Z controller and a VL406T panel.

Whats your email so we can get in touch?
—
Reply to this email directly,
view it on GitHub, or
unsubscribe.
You are receiving this because you commented.Message
 ID: ***@***.***>

Closed 2023-11-26.

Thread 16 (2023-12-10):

What about the second connector on the board

Zetto12, 2023-12-10:
Hi Guys,

First of thank you for publishing this project. My Spa controller (Balboa CPGS501Z) has two identical RJ45 connectors. One the Display is plugged in but the other one is empty.

Does the D1 Mini need to go in line with the display or can it be connected directly to the second port? I believe that is where the original WIFI controller is connected to.

Thank you

MagnusPer, 2023-12-10:
@Zetto12 - During the development I tested the "empty" RJ45 connector but it didn't worked and decided to not spend much investigation on why.

StarkJohan, 2024-04-15:
The secondary port is used for an IR receiver like this: https://www.tubs.parts/en/ir-receiver-for-balboa-gs5-systems-p-1509.html (two versions depending on the hardware/software version).
It would probably be possible to use that input but you'd have to figure out how the IR signals interact with the board. One idea I had was that the signal from the IR receiver might be using pin 1+2. That's a complete guess though.
Does the display work in both J1 and J2? I would assume so but I haven't tested.

Closed 2024-01-13.

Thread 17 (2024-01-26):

Gs514sz with vl702s topside hasn’t got full functionality

awallace24335, 2024-01-26:
Hello and thank you so much for this project.

I have set everything up using the HA example and 1/2 of the functions seem to work fine and the rest don’t.

The functions that are not functioning are:
Mode button
Temp up
Temp down
Lights button + lights
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
on data

Heater status, pump 1, pump 2, display data and temp all work fine.

My topside is slightly different being the Vl702s so wondering if there could be a slight variation in  the coding.

is there anything I can try to do, to get this fully functioning.

Many thanks

awallace24335, 2024-01-26:
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

MagnusPer, 2024-01-27:
Since that display is different than I developed the code for you need to go back to the basis. The only way I figured out was to study the communication behaviour between the control unit and the display using oscilloscope to determine and mimic each button push.

MagnusPer, 2024-01-27:
If you using the https://github.com/MagnusPer/Balboa-GS510SZ/tree/main/examples/Balboa_GS_Read example and try increasing the temp by enter  “1” in serial consol does anything change on display?

awallace24335, 2024-01-28:
Thank you for your comment,
 after doing some investigating most of the functions that a written through the serial console work as expected. the only problem is when I press "7" it activates the lights and pressing "4" has no response. How would I change these functions around?

I know just need to plug the board back in with the Home Assistant  firmware on to see if that works as expected.

Thank you for your help.

netmindz, 2024-01-28:
Are you using the MQTT example or this one examples/Balboa_GS_HomeAssistant/Balboa_GS_HomeAssistant.ino @awallace24335 ?

netmindz, 2024-01-28:
Try adding a space in the name here so the command mapping matches the name of this button.
I don't own this tub so wasn't able to fully test myself

https://github.com/MagnusPer/Balboa-GS510SZ/blob/46f41fbbb927061c465f90602a6bfaaeec2079b3/examples/Balboa_GS_HomeAssistant/Balboa_GS_HomeAssistant.ino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

awallace24335, 2024-01-28:
> Are you using the MQTT example or this one examples/Balboa_GS_HomeAssistant/Balboa_GS_HomeAssistant.ino @awallace24335 ?

I was trying to use the Home assistant example but I could get the temp commands working. I then started from the start and used the read example which was working other than lights / pump3 was mixed up.

I have just tried the Mqtt example and I can get everything working other that the lights / pump3 being mixed up, so i thing there must be a problem in the home assistant example

netmindz, 2024-01-28:
Yeah there is a fault in the home assistant example, the line I listed should be "Temp Up” not "TempUp" and similar for down

awallace24335, 2024-01-28:
> Try adding a space in the name here so the command mapping matches the name of this button. I don't own this tub so wasn't able to fully test myself
>
> https://github.com/MagnusPer/Balboa-GS510SZ/blob/46f41fbbb927061c465f90602a6bfaaeec2079b3/examples/Balboa_GS_HomeAssistant/Balboa_GS_HomeAssistant.ino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

adding this space on both up and down fixed this issue of the Temp Up and Temp Down commands. The only thing that I am missing is the Climate option (temp) I don't think its receiving all the values.

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

Thank you

awallace24335, 2024-01-28:
> Yeah there is a fault in the home assistant example, the line I listed should be "Temp Up” not "TempUp" and similar for down

I'm not really sure fully how I fixed it but all seems to be working. I did make some alterations to the code.

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

https://pastebin.com/xWgw1sWf

netmindz, 2024-01-29:
The current and target match between the climate and sensors in that image, so I'm guessing you mean the spa itself hasn't changed?

awallace24335, 2024-01-29:
> The current and target match between the climate and sensors in that image, so I'm guessing you mean the spa itself hasn't changed?

Correct, the only reason the target temp works is because i added "hvac.setTargetTemperature(Balboa.setTemperature);" which i now believe is wrong.
to fix the water temp i changed "hvac.setCurrentTargetTemperature(Balboa.waterTemperature);" to "hvac.setCurrentTemperature(Balboa.waterTemperature);"

when i press pump 3 it activates the lights, do you know if this can be switched around?

thank you for your help

netmindz, 2024-01-30:
Clearly different outputs have been used on your controller to the author of the library

Just swap this line

else if (s_payload == "Pump3") {

With the line about light

awallace24335, 2024-01-31:
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

No problem i will do that. Thank you

I don't think the status is tracked of Pump 3 to verify if its on or not. Is it possible to add it here or will it not work?

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

netmindz, 2024-04-18:
I've created a PR with some untested code that might help you along https://github.com/MagnusPer/Balboa-GS510SZ/pull/19

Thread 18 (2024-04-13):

Hello, I don't suppose anyone in the UK could either offer for sale the PCB including or gates, or give clear instructions how to purchase the made up PCB including components from an online UK PCB maker. I'm struggling with this, many thanks for any pointers (for MS500ZE unit in Masterspa GL2) with RJ45 socket).

doctorphilt, 2024-04-13:

netmindz, 2024-04-13:
Do you know that your board is actually a Balboa control system, just by another model number or is that a typo in your post?

Just the use of an RJ45 connector isn't sufficient to know compatibility

doctorphilt, 2024-04-14:
Thanks for getting back to me. Yes it is definitely a Balboa. It full "agency model" number is GS5-MS500ZE-RCA-2.0K. It has a standard Balboa GS casing.

StarkJohan, 2024-04-15:
I started decoding the protocol about four years ago but neither had the time or the grit to get it sorted and had to shelve it at that point. I just discovered this project and my aim is to get it up and running in before summer hits here in Sweden. I intend to order a PCB and as MOQ is 10 pcs I will likely have a few spare ones. I will make no promises at this point but I know my way around PCB design and this is a very basic board. I just need to have closer look at the details.

doctorphilt, 2024-04-15:
That would be wonderful if you had one spare / for sale 😃 Not sure we would communicate that if /when happened?

StarkJohan, 2024-04-21:
Unfortunately the protocol is different as well as the pinout. 5VDC is on pin 1. GND, display and clock are the same but I'm yet to find the button data. The other three pins are some kind of low voltage copy of the display data about 1.5V max representing a 1 and approximately half that representing a 0.
Also, there's 3x7bits + 1x3bits on the display line. Collecting data now to see if I can figure it out.
So far all I know is that the middle bit of the last 3-bit chunk is the ligjhts...

StarkJohan, 2024-06-09:
I've ordered a bare PCB that should be compatible with the following controllers and their equivalents:
"Mini": VL200, VL240, VL260, VL400, VL401, VL402, VL403, VL404, VL406T, VL406U
"Deluxe": VL600S, VL601S, VL700S, VL701S, VL702S

The pinout, the protocol and the exact functions differ a bit between the two groups.
The pinout is easily adjusted with a couple of jumpers in my design.
The software needs a slight adjustment for the "deluxe" panels but rather large changes to be compatible with the "mini" models. I've got a POC running nicely since a few weeks and I will publish a repo as soon as I've had the time to tidy up everything a bit.

I will be populating a few of the PCBs in the coming month so if anyone is keen on testing/developing on any other panel than VL406U or VL700S, please let me know below. If everything checks out I will be open sourcing the hardware design as well as the altered code I'm using.

doctorphilt, 2024-06-09:
Hi again, I think mine is VL400 but I would be very keen to trial one (within my limited electronics ability) or purchase one...

StarkJohan, 2024-06-09:
VL400 has one button for temp, mine has up and down buttons for temps so while the physical input is very likely to be the same, the exact function might differ slightly and thus the software would need to be slightly different. If you are a bit familiar with the software side of things you should be able to adjust the code accordingly.

Exactly what is the procedure to change temp from your VL400 controller?

On my controller the current temp is showed by default. If I push up or down once the set temperature starts flashing slowly. Then for every push up/down the set temp changes 1 degree. After a short timeout the flashing stops and the current temp is shown.

I can't offer any PCBs for free but I'll be offering this run at a price that covers my costs.

doctorphilt, 2024-06-09:
Mine must be a VL406U then as it has two buttons for temperature. The instruction manual said it was one or other (attached). I would be very happy to purchase one off you – not sure how we would do this on here, not sure how we are supposed to swap contact details but happy to publish my email address if no other way…

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

doctorphilt, 2024-06-30:
My contact is pjturner AT doctorsDOTorgDOTuk in case this helps:)

StarkJohan, 2024-07-12:
I've sent you an email with some info on current state of the PCB.

colsonpete, 2024-07-27:
I am UK based and I’d be very interested too, and happy to pay for it.  I have a VL406T panel (so only 4 buttons: Jets 1, Jets2/Blower, Lights and Temp) connected to a GS515Z.

I bought MOC of 5 of the MagnusPer/Balboa-GS510SZ board last year (so have 4 spares) but couldn’t get it working as the pumps cycled on and off a couple of times a second.

I have since realised that I had connected the PCB to the second RJ45 socket on the controller PCB e.g. in parallel to the panel rather than in series with the panel. I have tried it again today (now wired correctly, I think) and it is no longer causing the pumps to cycle, so progress of sorts.

However, I am not getting anything out of MQTT so suspect you are right about the pinouts being different on the VL406 range.

Please let me know when you have anything ready for testing.

StarkJohan, 2024-07-28:
I have two extra PCBs finalized but the github repo is not ready for publishing yet. I'm caught up with a very big hardware project currently so everything else has been put on hold.

However. While the pinout is the same, the software has to be altered as the actual button functions are not the same. The basic function of reading the data, sending button presses and reading button presses from the panel should work as is.
I might just get a very basic POC project up on github with a general function test as I've been getting some interest in PCBs during the last months.
I'll charge €39 + shipping for a finished PCB at this point. Please send an email to johanATpunktvvvDOTse and we can get the details sorted.

badgeraudio, 2024-08-01:
Another interested party to the new project.
I have a GS500Z with I think a VL401. I have tracked it down to this so far.
Pin 1 +5v
Pin 2 lights
Pin 3 Jets
Pin 4 0V
Pin 5 Display
Pin 6 Display
Pin 7 Blower
Pin 8 Temp

Momentary pulling Pin 2/3/7/8 simulates a button press.
1 button press for temp makes it the display flash, a 2nd press reduces the set temp by one deg.
Once its stopped flashing (1 or 2 seconds), press it again to make it flash again
Then press temp again and it starts increasing the temp with the button presses.

I did try powering a wemos mini from the 5v line, and it didnt like it! In that the controller appeared to reboot and the voltage drops when the wemos is connected.
so we might need to have a separate psu within the spa.

s1dave-web, 2024-08-13:
Another UK citizen here hoping to automate my tub!

I have a 13amp StrongSpa G2 equipped with a GS501SZ and 5 Button VL701S.

@StarkJohan I will contact you via email for more details

adamwylde, 2024-08-28:
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

I’m very interested in this too. I have a GS500Z unit with VL401 (2 speed pump/lights/temp up/temp down). Are you close to publishing please @StarkJohan? Many thanks

StarkJohan, 2024-08-28:
Outside of work I've been very busy with another hardware project the last month or so but the PCB has been running nicely installed in my own tub for quite some time now. I really intend to get back to this in the next few weeks, I promise! I need the code to be more dynamic for my own install as well so it's just a matter of time. Please be patient and I'll keep you posted.
As it seems, even if the PCB is compatible with a range of different displays, the software will need adjustments to match the different ways the displays work. My plan is to publish a very basic POC and the example I've adapted to my specific panel. Then we'll have to adapt the code to as many displays as possible. Expect some coding and testing!

adamwylde, 2024-08-28:
Great. My son is great with electronics and I’m a software developer (although not in C++ normally!) so very happy to, and capable of getting a PCB ordered from Gerber files, and play with some code. We’ve already done the same for this GS510 project before realising our display is too different to make use of the board.

StarkJohan, 2024-08-28:
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
This is the preliminary design, it needs a few small adjustments but it plugs straight into the main pcb.

adamwylde, 2024-09-22:
Hey @StarkJohan got any further this this?

Still keen to help/beta/get made up, especially as the cold season approaches!

I’d like to be able to manipulate when the hot tub heats via home asssistant to make use of our cheap overnight electricity.

Many thanks

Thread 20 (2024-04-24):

Resistor Value Confirmation

cap60552, 2024-04-24:
In your schematic you call for a 370ohm resistor as what ends up being R2 on the PCB.   I've been unable to locate a 370ohm size 0603 resistor.   Is this possibly supposed to be 470, or 330?  and if not, would either of those work in place of the 370?  I'm assuming the 470 would probably be ok since its current limiting on the opto-isolator, but I wanted to get confirmation.

MagnusPer, 2024-04-24:
@cap60552 - There should be available 370 ohm 0602 size resistor, I just goggle it and found a number of suppliers! However a 470 ohm resistor should also work fine, have not tested it though!

Closed 2024-05-26.

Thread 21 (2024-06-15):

CalSpas 407T and CS6215R1A

smitterer, 2024-06-15:
Hi!

I have a Cal Spa CS6215R1A which seems to be some special version of GS500Z with a Cal Spa 407T Display.

Here are some images:
https://photos.app.goo.gl/NoeShParJBgJhQFB9
https://photos.app.goo.gl/DKkjtgdfRPYoWXpB6

Do you have an idea if your project would work with our controller?

Thanks!

mperss54, 2024-06-17:
Hi,
Sorry don't have the knowledge to answer your question about compatibility between CAL SPA control system and the GS510SZ I used as reference during the development.

MagnusPer, 2024-06-17:
Hi,
Sorry but I don't have the knowledge to answer your question about compatibility between CAL SPA control system and the GS510SZ I used as reference during the development.

smitterer, 2024-06-17:
Ok thx.

But ordering the PCB from JLCPCB and connecting it shouldn't be an issue/dangerous due to the same base of the Spa-PCB I guess?

I'd then "just" need to change the code to address the different buttons.

Thanks

MagnusPer, 2024-06-17:
That I can't confirm since I don't have the knowledge of your system

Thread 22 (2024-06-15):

TXGA FRJ45007-1100K6K02B0 not available

smitterer, 2024-06-15:
Hi!

The TXGA FRJ45007-1100K6K02B0 isn't available at jlcpcb.

Does someone know an alternative?

Thanks

mperss54, 2024-06-17:
I don't know the part numbers but you can use whatever RJ45 connector available

MagnusPer, 2024-06-17:
Hi,
I don't know the part numbers but you can use whatever RJ45 connector available

smitterer, 2024-06-17:
So JLCPCB suggested this one: C54408

MagnusPer, 2024-06-17:
That component will do the job equally good

s1dave-web, 2024-08-30:
Just an FYI I tried to order the PCB with C54408 but it has 10 pins instead of 8 and 2 extra holding pins at the front so JLC paused my order, luckily the originals are now in stock

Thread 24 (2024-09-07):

GS501SZ + 5 Button VL701S - No Display Data

s1dave-web, 2024-09-07:
Hi Guys,

I have a StrongSpa G2 with Balboa GS501SZ + 5 Button VL701S top panel.

I have the PCB setup by JLCPCB and connected to the Spa as follows:
DISPLAY-------->(RJ1) PCB (RJ2)--------->(J1)Control system

I am using a standard RJ45 cable that came spare with my router between PCB and Control System

My initial issue is I don't seem to get accurate states or display data:

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

Buttons seem to function OK for the most part with Balboa_GS_Read over serial:
1 - OK - Temp goes up
2 - OK - Temp comes down
3 - OK - Mode functions as expected when used with 1/2
4 - OK - Light cycles on/off when sending 4
5 - OK - Pump activates low setting, sending again activates high setting, sending again sets pump to off
6 - NA - No 2nd Pump
7 - NA - No 3rd Pump
8 - Causes a loop to lowest temperature and display will not accept any input
9 - Causes a loop to lowest temperature and display will not accept any input

So it would appear most buttons function as expected other than 8/9 which should be fine for my needs - any help on the display data?

Also when using Balboa_GS_HomeAssistant the light button doesn't seem to work but is perfect over serial with Balboa_GS_Read

netmindz, 2024-09-08:
Looks like I made an error on this line. It should be lights plural

https://github.com/MagnusPer/Balboa-GS510SZ/blob/46f41fbbb927061c465f90602a6bfaaeec2079b3/examples/Balboa_GS_HomeAssistant/Balboa_GS_HomeAssistant.ino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

s1dave-web, 2024-09-08:
Buttons function as expected now thank you @netmindz

Balboa_GS_HomeAssistant had the following adjustments:
Line 252 change if (s_payload == "TempUp") { to if (s_payload == "Temp Up") {
Line 256 change else if (s_payload == "TempDown") { to else if (s_payload == "Temp Down") {
Line 260 change else if (s_payload == "Light") {  to else if (s_payload == "Lights") {

Now just need to work out how to get display, heater, light, pump and water temp data

netmindz, 2024-09-08:
Glad you sorted it, do you know how to create a PR to submit your fix?

As for displaying the state, that in theory should already be sent to HA

Does HA not show the current state of the lights if you toggle on the tub for example?

s1dave-web, 2024-09-08:
I think I have submitted a PR now after watching a YT tutorial...

HA is receiving the state data, its just incorrect (everything shows in ON state and does not change, display shows 88.88 and Water temp 0c)

I can only think that maybe the GS501SZ differs to the GS510SZ when sending state data? Or possibly my read & clock pins are not getting a proper connection... I will inspect the board for continuity tomorrow but suspect it is OK as panel on tub is 100% functional.

netmindz, 2024-09-08:
Yeah if the values are wrong when looking at the serial output, then not an issue with the home assistant part so I'll stand down

s1dave-web, 2024-09-09:
Great progress today - A new Mini D1 fitted and I now have display data. I will close this issue and open a new one for the last remaining issue - HVAC controls.

Closed 2024-09-09.

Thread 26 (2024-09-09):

HA HVAC control - unable to change Target Temperature

s1dave-web, 2024-09-09:
With a new D1 mini I now have a fully working setup with sensor and display data on my GS501SZ + 5 Button VL701S:
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

The only part not functioning is HVAC - so far I have managed to get it to have the correct current and target temperature by changing line 222:
deleted:
          hvac.setCurrentTargetTemperature(Balboa.waterTemperature);

added:
          hvac.setCurrentTemperature(Balboa.waterTemperature);
          hvac.setTargetTemperature(Balboa.setTemperature);

Ultimate goal would be to get temperature changes on the HVAC card to increase the setTemperature value.
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

I have a feeling something with onTargetTemperatureCommand should be changing temps:
```
void onTargetTemperatureCommand(HANumeric temperature, HAHVAC* sender) {
    float temperatureFloat = temperature.toFloat();

    Serial.print("Target Temperature: ");
    Serial.println(temperatureFloat);

    Balboa.updateTemperature(temperatureFloat);

    sender->setTargetTemperature(temperature); // report target temperature back to the HA panel
}
```

But I am a bit stuck... hoping someone with ArduinoHA knowledge could help... @netmindz possibly?

netmindz, 2024-09-09:
The changes look correct, if you logger is showing the right target value when you change, then it's an issue with the set temp call in the library

s1dave-web, 2024-09-10:
Serial monitor shows nothing when changing the temp on the HVAC card

Using Balboa_GS_Read.ino sending case 8 and 9 work fine... so it would appear HA isn't sending command

s1dave-web, 2024-09-10:
Is there a simpler way without using HVAC card that I can set the temperature to a specific value within HA? At the moment the only way would be to send Temp Up a certain amount of times.

netmindz, 2024-09-10:
It's missing

hvac.onTargetTemperatureCommand(onTargetTemperatureCommand);

s1dave-web, 2024-09-10:
That was it... so silly of me!

I am going to make a PR with a new file for 1 pump tubs because the new version of the current file has changed to switches which does not work for me as I need to be able to press pump1 twice to alternate speeds so button works best.

s1dave-web, 2024-09-10:
That was it... so silly of me!

I am going to make a PR with a new file for 1 pump tubs because the new version of the current file has changed to switches which does not work for me as I need to be able to press pump1 twice to alternate speeds so button works best.

Closed 2024-09-10.

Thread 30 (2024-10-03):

ESP yaml help

Doser86, 2024-10-03:
I am unable to install the Balboa_GS_HomeAssistant.ino
Getting a lot of errors in the yaml.

netmindz, 2024-10-03:
The file is a sketch you build with the ArduinoIDE and populate with the connection details to the MQTT server that is attached to your Home Assistant setup

You make no modification to any yaml to use this code

Doser86, 2024-10-03:
Aaaahhh. Sorry. I am only used to flashing with ESPhome.
So only flashing this file with Arduino IDE and nothing more? Mqtt server i allready have.

netmindz, 2024-10-03:
No worries. Yeah just need to set the right connection details before you flash

Doser86, 2024-10-03:
Thankyou :)

I messure different in my RJ45. pin 1 is about 5v. Pin 4 i ground. How do I messure wich is data kables?

Doser86, 2024-10-04:
I get no readings. Tried every combination with wires. Do I have to have the board you are using? I installed the code on a Atom M5-stack.

netmindz, 2024-10-04:
Are you sure your controller is the GS510SZ ?

Doser86, 2024-10-04:
Is this on the cover of the pump? I have a GS, that I know. Inside the cover is saying MS500ZE - PN 56861

netmindz, 2024-10-04:
So that is a different model, you would need to research if the topside controls for the GS500Z are also compatible with the GS510SZ

netmindz, 2024-10-04:
The GS510 says "Topside controls from the serial standard VL range such as the VL700S and the VL701S"

The GS500 says "It pairs excellently with topside controls from the duplex VL range, such as the VL404 and MVP260. However, it’s most commonly used with the Mini Panel VL200."

So different controls so this library won't be compatible

Doser86, 2024-10-05:
But this should just be finding the data from VL200 and change the include files right?

netmindz, 2024-10-05:
My point is that this code won't work with your tub.
Your task is to understand what the differences are between the two systems and then create new code, probably using this as your starting point, but having it's own feature set.
As this is the same manufacturer, it's most likely their own code is a respin of what they have done before, you just need to find out what extra capabilities and changes they made with your board.
At the end of the day we are emulating the topside controls, not the controller

Doser86, 2024-10-05:
This is exactly what I was thinking. How did you find out yours is working?

netmindz, 2024-10-05:
My own tub uses a totally different communication method, so I had to reverse engineer their serial protocol

Doser86, 2024-10-06:
This is a little bit above my knowledge I think

Doser86, 2024-10-08:
My board is saying: When J12 on the Main Board is jumpered on pins 2 & 3, the system is in GS50xZ compatibly mode.

If J12 on the Main Board is jumpered on pins 1& 2, the system is in GS51xZ/GS5xxSZ/GS5xxDZ compatibly mode.

Maybe solution is here?

netmindz, 2024-10-08:
Worth a try, however you may well then use some/all use of your current topside controls, which may or may not be an issue. In the worse case you might apply the wrong power to the wrong pins and cause damage to your existing topside control, so best to check exactly what that change of setting does without the topside panel attached

Doser86, 2024-10-08:
I try tonight without the top panel connected. If this works then I could just buy a new panel than works or make a switch to switch between HA and top panel

Doser86, 2024-10-09:
Should I have both Balboa_GS_Interface.cpp and Balboa_GS:Interface.h in the sketch map? I am not able to flash when I have them in the same folder.

netmindz, 2024-10-09:
This is a library. You need to add  the entire project into the library folder for your identity, then open one of the examples from the examples menu in the ide

Doser86, 2024-10-09:
Sorry for stupid questions. Is there like one zip folder that has ewerything in it?

netmindz, 2024-10-09:
https://github.com/MagnusPer/Balboa-GS510SZ/archive/refs/heads/main.zip

Doser86, 2024-10-09:
So I "Include library" - "Add zip.library" - then go to exampels and open lets say Balboa_GS_HomeAssistant. Then just change my wifi, server and mqtt?

First time using Arduino IDE

Doser86, 2024-10-09:
Nothing more? Then just flash?

Doser86, 2024-10-16:
Your wiring thru EL816... Is this necasarry? Or kan I just go straight from Balboa read and write wires an in to D2 and D8?
How did you messure wich wires this was on your tub?

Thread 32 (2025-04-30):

Question about How it works

koalatje2000, 2025-04-30:
Hello, I'm working on this project too, and I aim to get it running on the display's second port. I have a couple of questions regarding the transmission of button data:

- Can I simply send 3 bits of button data followed by 3 clock pulses directly to the print, and will that work as intended?
- Or should I transmit both the display and button data over the line, since the 3 bits are follow-up bits within the display message?

Additionally, in your setup—where you're positioned between the controller and the display cable—do you use the full message and swap only the last 3 bits, or do you send a new request during the roughly ±16ms interval when the display isn't communicating?

Thank you in advance. Once I get it working, I'll showcase my system. Hopefully, it can help you improve yours.

Best regards,
Wouter

MagnusPer, 2025-05-03:
Hi @koalatje2000

I tried the second port during developmend but I nerver get it to work! Perhaps I didn’t put enough time to sort out why.

The code calculates the message sent between controller and display and simulates button presses on the bit positions explained in description, section [button-data](https://github.com/MagnusPer/Balboa-GS510SZ#button-data). The only thing you need to simulate is the button pushes

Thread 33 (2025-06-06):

GS500Z with Balboa-VL260-PN-55081 control panel

surfmk, 2025-06-06:
Hi all,

This is a great project! I have a Cove Spa Delux that came with my house and I'm getting into home automation.

Before I jump into this and get my soldering iron out, could anyone comment on:

1. Code compatibility with GS500Z and my 4 button VL260?
    I'm happy to do some code editing and have a hobbie background in C++

2. I have a LAN connection available I would like to use in preference to Wemos D1 mini
    (powerline LAN allows extra distance into garden - out of wireless range)

I attach some photos of my actual hardware...

Many thanks in advance,

Paul

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

MagnusPer, 2025-06-07:
Hi @surfmk
Nice you visit this GitHub project! I can not answer the question on compatibility for your GS500Z control system since I reversed engineered GS510SZ. Either you need to do the same approach I did to measure the link between control system and display using oscilloscope or just give it a try and hope for the best!

Jacktheripper125, 2025-06-26:
Hi, I can confirm it doesnt work sadly. It stops the pump button from working and no useful data is gained.

surfmk, 2025-06-26:
Hi Jack, That's interesting you are following this up... I haven't started yet but am happy to see what protocols are being used when I do. I'd quite to find a remote panel (chances are remote!) and see if we can replicate the signals that this sends...
All good fun.
Paul

netmindz, 2025-07-03:
You might find a logic analyser is more helpful than a scope

Jacktheripper125, 2025-07-03:
Thank you netminds.

One thing i would say is dont try the software and card on a gs500. After usung it my hot tub went to 40c and stayed there even though i selected 34c it just kept heating to 40c after haveing the card plugged in. I tried re powering and re setting. Even tried a new temp sensor. I have now had the tub un plugged a few days and the memory wipe jumper on and touch wood today it is back to normal.
I will maybe wait until i get brave again. I will get a logic board as it looks interesting. I will find something cheaper to break first

surfmk, 2025-07-21:
Hi Jack, just wondering if any more progress? A logic analyser seems to be the way forward as netmindz suggested. I'll try to learn a bit more about how these work as I've only ever used an oscilloscope. If we can work out the protocol, we should be able to see where it diverges from the GS510*Z.

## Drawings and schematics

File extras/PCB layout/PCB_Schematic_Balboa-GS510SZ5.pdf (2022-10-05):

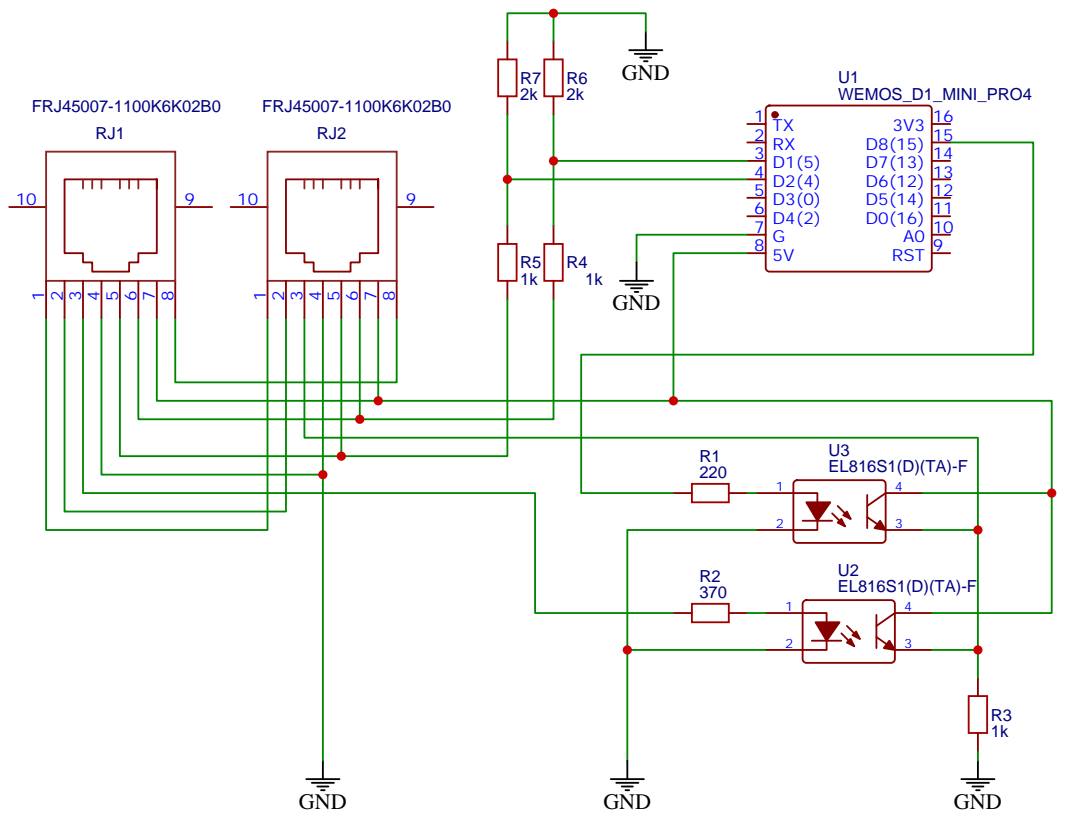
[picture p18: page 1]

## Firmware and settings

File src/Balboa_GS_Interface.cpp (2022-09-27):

#include "Balboa_GS_Interface.h" 


byte BalboaInterface::clockPin;
byte BalboaInterface::displayPin;
byte BalboaInterface::buttonPin;
bool BalboaInterface::displayDataBufferOverflow;
bool BalboaInterface::writeDisplayData;       
bool BalboaInterface::writeMode;
bool BalboaInterface::writeTempUp;
bool BalboaInterface::writeTempDown;
bool BalboaInterface::writeLight;
bool BalboaInterface::writePump1;
bool BalboaInterface::writePump2;
bool BalboaInterface::writePump3;
unsigned long BalboaInterface::clockInterruptTime;
int  BalboaInterface::clockBitCounter;  
byte BalboaInterface::displayDataBuffer[displayDataBufferSize];
byte BalboaInterface::dataIndex; 
bool BalboaInterface::displayDataBufferReady;  


BalboaInterface::BalboaInterface(byte setClockPin, byte setReadPin, byte setWritePin) {
  clockPin = setClockPin;
  displayPin = setReadPin;
  buttonPin = setWritePin;
     
}

void BalboaInterface::begin() { 
  pinMode(clockPin, INPUT);
  pinMode(displayPin, INPUT);
  pinMode(buttonPin, OUTPUT);
  digitalWrite(buttonPin,LOW);   
   
  attachInterrupt(clockPin, clockPinInterrupt, CHANGE);
  
 }

void BalboaInterface::stop() {
  
  detachInterrupt(digitalPinToInterrupt(clockPin));    

}

bool BalboaInterface::loop() {

	if (displayDataBufferReady) { 
		
		// Decode data onces available 
		decodeDisplayData(); 
		
		// Get setTemperature if not known 
		if (setTemperature == 0) {
			writeDisplayData = true;
			writeTempUp = true;
		}
				
		
		// Update temperature 
		if (updateTempButtonPresses > 0) {
			
			if(millis() - buttonPressTimerPrevMillis  > buttonPressTimerMillis) {
				
				buttonPressTimerPrevMillis = millis();

				if (updateTempDirection == 1) {
					writeDisplayData = true;
					writeTempDown = true;
				}
				else if (updateTempDirection == 2) {
					writeDisplayData = true;
					writeTempUp = true;
				}
			
				updateTempButtonPresses--;
			}
		}
	}
	   	
  return true;	
}


void BalboaInterface::updateTemperature(float Temperature){
	
	float updateTempDifference = Temperature - setTemperature;
	
	if (updateTempDifference < 0 ) 		 { updateTempDirection = 1; }			// Temp down
	else if (updateTempDifference > 0 )  { updateTempDirection = 2; }			// Temp up
	else if (updateTempDifference == 0 ) { updateTempDirection = 0; }			// no change
	
	updateTempButtonPresses = 1 + (abs(updateTempDifference) * 2);				// calculate how many times the "button" should be pressed 
																				// every button press = 0.5 and the first is to enter the menu																			
}
	
	
void BalboaInterface::decodeDisplayData() {

      LCD_segment_1 = 0;
      LCD_segment_2 = 0;
      LCD_segment_3 = 0;
      LCD_segment_4 = 0;
      
      LCD_display = "";
            
      for (int x = 0; x <= displayDataBits; x++) {
      
                  if ( x <= 6 ) {
                        LCD_segment_1 <<= 1;
                        if (displayDataBuffer[x] == 1){
                            LCD_segment_1 |= 1;
                        }
                        else LCD_segment_1 |= 0;
                  }
                  else if (x > 6 && x <= 13) {
                        LCD_segment_2 <<= 1;
                        if ( displayDataBuffer[x] == 1){
                            LCD_segment_2 |= 1;
                        }
                        else LCD_segment_2 |= 0;
                  }   
                  else if (x > 13 && x <= 20) {
                        LCD_segment_3 <<= 1;
                        if ( displayDataBuffer[x] == 1){
                            LCD_segment_3 |= 1;
                        }
                        else LCD_segment_3 |= 0;
                  }   
                  else if (x > 20 && x <= 27) {
                        LCD_segment_4 <<= 1;
                        if ( displayDataBuffer[x] == 1){
                            LCD_segment_4 |= 1;
                        }
                        else LCD_segment_4 |= 0;
                  }       
                  else if (x == 28) {
                        if ( displayDataBuffer[x] == 1){
                            displayButton = true;
                        }
                        else displayButton = false;
                 }
                 else if (x == 29) {
                        if ( displayDataBuffer[x] == 1){
                            displayBit29 = true;
                        }
                        else displayBit29 = false;
                 } 
                  else if (x == 30) {
                        if ( displayDataBuffer[x] == 1){
                            displayBit30 = true;
                        }
                        else displayBit30 = false;
                  }  
                  else if (x == 31) {
                        if ( displayDataBuffer[x] == 1){
                            displayStandardMode = true;
                        }
                        else displayStandardMode = false;
                  } 
                  else if (x == 31) {
                        if ( displayDataBuffer[x] == 1){
                            displayStandardMode = true;
                        }
                        else displayStandardMode = false;
                  } 
                  else if (x == 32) {
                        if ( displayDataBuffer[x] == 1){
                            displayBit32 = true;
                        }
                        else displayBit32 = false;
                  } 
                  else if (x == 33) {
                        if ( displayDataBuffer[x] == 1){
                            displayBit33 = true;
                        }
                        else displayBit33 = false;
                  } 
                  else if (x == 34) {
                        if ( displayDataBuffer[x] == 1){
                            displayBit34 = true;
                        }
                        else displayBit34 = false;
                  } 
                  else if (x == 35) {
                        if ( displayDataBuffer[x] == 1){
                            displayHeater = true;
                        }
                        else displayHeater = false;
                  } 
                  else if (x == 36) {
                        if ( displayDataBuffer[x] == 1){
                            displayPump1 = true;
                        }
                        else displayPump1 = false;
                  } 
                  else if (x == 37) {
                        if ( displayDataBuffer[x] == 1){
                            displayPump2 = true;
                        }
                        else displayPump2 = false;
                  }   
                  else if (x == 38) {
                        if ( displayDataBuffer[x] == 1){
                            displayLight = true;
                        }
                        else displayLight = false;
                  }   
                 
            } 
        
           LCD_display_1 = lockup_LCD_character(LCD_segment_1);
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

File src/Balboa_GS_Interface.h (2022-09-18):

#ifndef Balboa_GS_Interface_h
#define Balboa_GS_Interface_h

#include <Arduino.h>


const byte displayDataBufferSize       		= 40;		// Size of display data buffer
const byte displayDataBits             		= 38;       // 0-38 bits length of display data within a cycle
const byte buttonDataBits              		= 2;        // 0-2 bits length of button data within a cycle
const byte totalDataBits               		= 41;       // 0-41 total number of pulses within a cycle
const unsigned int durationNewCycle    		= 5000;		// How many microsecounds to detect new cycle if no interrupt occurs 
const unsigned long buttonPressTimerMillis  = 500;  	// Timer in milliseconds between update temperature button presses 


class BalboaInterface {

  public:
	
	BalboaInterface(byte setClockPin, byte setReadPin, byte setWritePin);
	
	// Interface control
	void begin();						           	// Initializes the stream output to Serial by default
    bool loop();                                    // Returns true if valid data is available
    void stop();                                    // Disables the clock hardware interrupt 
    void resetStatus();                             // Resets the state of all status components as changed for sketches to get the current status	
	void updateTemperature(float Temperature);		// Function to set the water temperature 	

	// Status tracking
	float waterTemperature;                			// Water temperatur 
	float setTemperature;                			// The wanted set temperature   
	String LCD_display;								// The text shown on display 
	bool displayButton;        						// Temp up/down button pressed
	bool displayBit29;        						// Still unknown functionality, if at all used!
	bool displayBit30;        						// Still unknown functionality, if at all used!
	bool displayStandardMode;        				// Standard Mode activated or not
	bool displayBit32;        						// Still unknown functionality, if at all used!
	bool displayBit33;        						// Still unknown functionality, if at all used!  
	bool displayBit34;        						// Still unknown functionality, if at all used!
	bool displayHeater;        						// Heater running or not
	bool displayPump1;        						// Pump 1 running or not 
	bool displayPump2;        						// Pump 2 running or not
	bool displayLight;        						// Hot tube lights activated or not
	static bool displayDataBufferOverflow;
	
	// Write button data to control unit  
	static bool writeDisplayData;            		// If something should be written to button data line  
	static bool writeMode;
	static bool writeTempUp;
	static bool writeTempDown;
	static bool writeLight;
	static bool writePump1;
	static bool writePump2;		
	static bool writePump3;

  private:
	
	static void clockPinInterrupt();
	void decodeDisplayData();
	String lockup_LCD_character(int LCD_character);
	int LCD_segment_1;
	int LCD_segment_2;
	int LCD_segment_3;
	int LCD_segment_4;
	String LCD_display_1;
	String LCD_display_2;
	String LCD_display_3;
	String LCD_display_4;  
	static byte displayDataBuffer[displayDataBufferSize]; 	// Array of display data measurements 
	static unsigned long clockInterruptTime;
	static int clockBitCounter;               		 		// Counter of pulses within a cycle
	static byte dataIndex; 									
	static bool displayDataBufferReady;            			// Is buffer available to be decoded
	static byte clockPin;
    static byte displayPin;
    static byte buttonPin;

	int updateTempDirection;
	int updateTempButtonPresses;
	unsigned long buttonPressTimerPrevMillis; 
};

  
#endif  // Balboa_GS_Interface_h

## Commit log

2022-09-27 Failure in the interpretation of "9"
    [Balboa_GS_Interface.cpp]
2022-10-05 PCB fabrication added
2022-10-13 Add files via upload
    Changed to ElegantOTA, added MQTT interface for Stop and Reset
    [Balboa_GS_MQTT.ino]
2022-12-10 PCB BOM list added
    [BOM_PCB_Balboa- GS510SZ_2022-10-05.csv]
2022-12-10 added PCB fabric files
    [BOM.xls, PickAndPlace_PCB_Balboa- GS510SZ_2022-12-10.csv]
2023-01-07 wiring diagram clarification
2023-09-02 Porting raw MQTT to HomeAssistant - add sensors
2023-09-02 ESP32 fix
2023-09-02 Add buttons to send command
2023-09-02 Move examples to correct folders
    [Balboa_GS_MQTT.ino, Balboa_GS_Read.ino]
2023-10-30 Add missing buttons and temp control
    [Balboa_GS_HomeAssistant.ino]
2023-11-12 Added ElegantOTA.loop();
    Added ElegantOTA.loop(); to fix OTA Update Problems
    [Balboa_GS_MQTT.ino]
2023-11-25 Added housing files
    I created a printable Case/ Housing for the ESP PCB
    [Bottom.stl, Top.stl]
